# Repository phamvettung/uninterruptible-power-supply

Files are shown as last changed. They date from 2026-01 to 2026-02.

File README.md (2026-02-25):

<div align="center">
 <h1>SUPERVISORY CONTROL AND DATA ACQUISITION ON ELECTRICITY IN INDUSTRIAL PLANTS</h1>
 <h2>HỆ THỐNG ĐIỀU KHIỂN, GIÁM SÁT VÀ THU THẬP DỮ LIỆU ĐIỆN NĂNG TRONG XÍ NGHIỆP CÔNG NGHIỆP</h2>
</div>

## Contents
- [1. Abstract](#i-abstract)
- [2. Design of Uninterruptible Power Supply for an Industrial Plant](#ii-design-of-uninterruptible-power-supply-for-an-industrial-plant)
- [3. Design of Control cabinet](#iii-design-of-control-cabinet)
- [4. SCADA for Power System](#iv-supervisory-control-and-data-acquisition-for-power-system)
- [5. Hidden Markov Model and Forecast Service](#v-hidden-markov-model-and-electricity-usage-forecasting-service)
- [6. Demonstration](#vi-demonstration)
- [7. Requirements](#vii-requirements)
- [8. References](#viii-references)

# I. ABSTRACT
<div>
 <p>This project is a modern SCADA model for the electrical system of an industrial plant. The model is developed based on the TCP/IP protocol, with the advantage stability, flexibility in building your own protocol and real-time communication.</p>
<p>Dự án là mô hình SCADA hiện đại cho một Xí nghiệp công nghiệp. Mô hình được phát triển dựa trên giao thức TCP/IP, với ưu điểm ổn định, linh hoạt trong việc tự định nghĩa giao thức và khả năng truyền thông theo thời gian thực.</p>
</div>

# II. DESIGN OF UNINTERRUPTIBLE POWER SUPPLY FOR AN INDUSTRIAL PLANT
<div>
 <p>Design a power supply for an industrial enterprise comprising 6 workshops, with power sourced from a 22kV connection point. Maximum power usage time Tmax = 5100 hours. Type I and Type II loads account for 75%. The calculated data is shown below.</p>
<p>Thiết kế hệ thống cấp điện cho một Xí nghiệp công nghiệp gồm 6 Phân xưởng, nguồn điện được lấy từ điểm đấu điện của lưới 22kV. Thời gian sử dụng công suất tối đa Tmax = 5100h. Phụ tải loại I, loại II chiếm 75%. Các số liệu tính toán được thể hiện ở bên dưới.</p>
<p align="center">
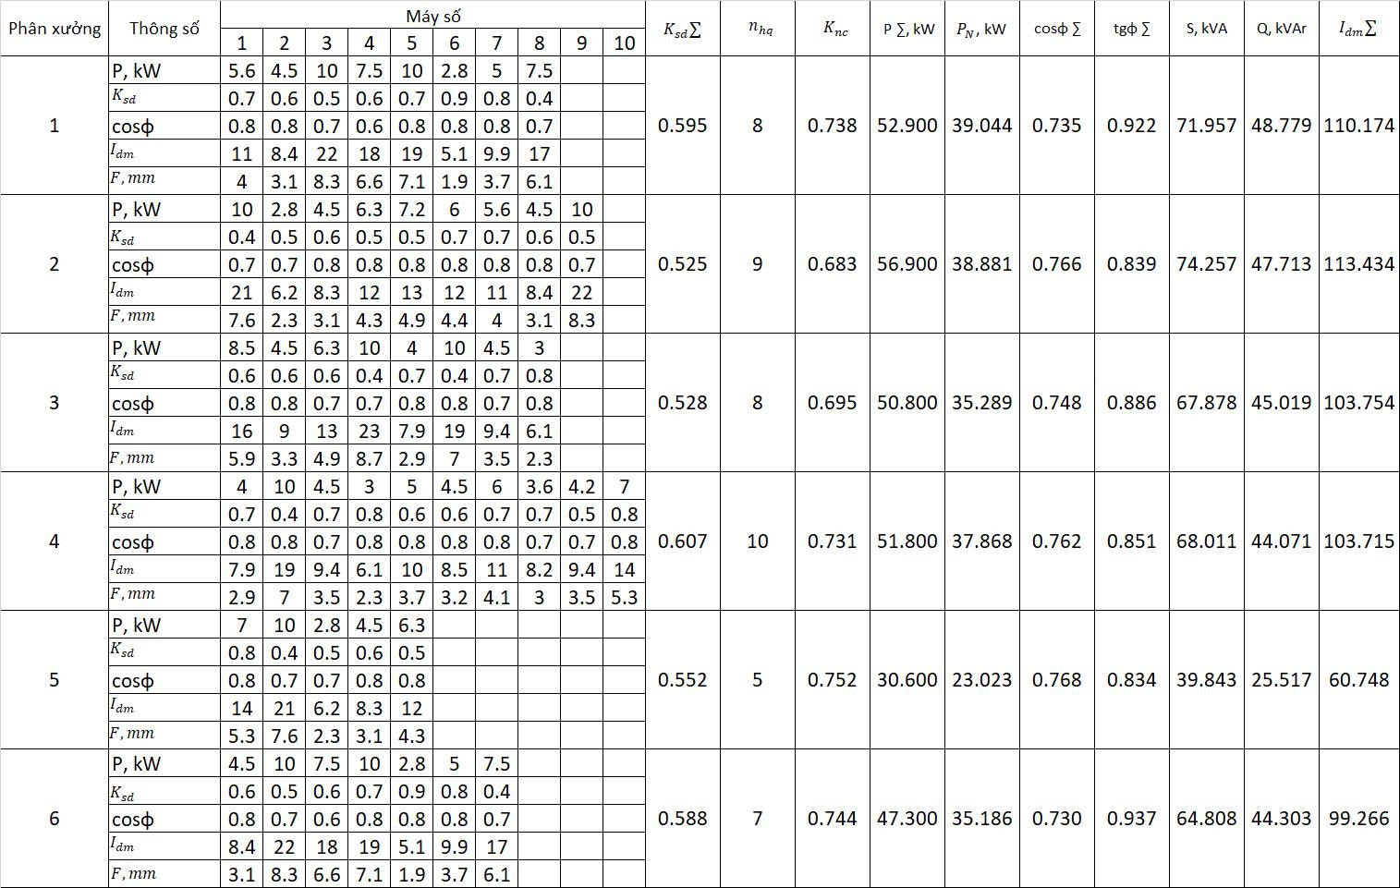
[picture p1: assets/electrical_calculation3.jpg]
  
</p>

#### a. Xác định phụ tải tính toán của toàn Xí nghiệp

**- Hệ số sử dụng của toàn Xí nghiệp:**

$$
K_{sd}XN = \frac{\sum (S_i \times K_{sd,i})}{\sum S_i} = 0.566
$$

**- Hệ số nhu cầu của Xí nghiệp:**

$$
K_{nc}XN = 0.566 + \frac{(1 - 0.566)}{\sqrt(6)} = 0.743
$$

**- Hệ số công suất trung bình của toàn Xí nghiệp:**

$$
\cos \varphi XN = \frac{\sum (S_i \times \cos_{\varphi,i})}{\sum S_i} = 0.75 => \sin \varphi = \sqrt{1-\cos^2 \varphi} = 0.66
$$

**- Tổng công suất tính toán của toàn Xí nghiệp:**

$$
S_{XN} = K_{nc}XN \times \sum S_i = 0.743 \times 386.75 = 287.48 kVA
$$

$$
P_{XN} = S_{XN} \times \cos \varphi_{XN} = 0.75 \times 287.48 = 215.781 kW
$$

$$
Q_{XN} = S_{XN} \times \sin \varphi_{XN} = 0.66 \times 287.48 = 189.95 kVAr
$$

**- Chọn dây dẫn từ nguồn đến trạm biến áp:**

>>Dòng điện chạy trên dây dẫn

$$
   I = \frac{S_{XN}}{\sqrt(3) \times U} = \frac{287.48}{\sqrt(3) \times 22} = 7.544 A
$$

>>Tiết diện dây nhôm theo mật độ dòng điện kinh tế (Jkt = 1.2 A/mm2). Đối với đường dây cao áp tiết diện tối thiểu không nhỏ hơn 35mm2 => Ta chọn dây AC-35 nối từ nguồn vào trạm biến áp

$$
   F = \frac{I}{J_{kt}} = \frac{7.544}{1.2} = 6.28 \text{mm}^2
$$

#### b. Chọn máy biến áp

>>Ta có tổng công suất tính toán toàn Xí nghiệp (chưa kể đến hao tổn công suất trên đường đây) = 287.48 kVA, thời gian sử dụng công suất tối đa = 5100 h

**- Công suất trung bình**

$$
   S_{tb} = \frac{S_{XN} \times T_{max}}{8760} = \frac{287.48 \times 5100}{8760} = 167.36 kVA
$$

**- Hệ số điền kín đồ thị phụ tải = 0.58 < 0.75. Như vậy máy biến áp có thể làm việc quá tải 40% (kqt = 1.4) trong một thời gian xác định**

$$
   k_{đk} = \frac{S_{tb}}{S_{XN}} = \frac{167.63}{287.48} = 0.58
$$

=> Chọn 02 máy biến áp có công suất định mức 2 x 250 kVA, hệ số quá tải = 0.99 nhỏ hơn 1.4 => đảm bảo yêu cầu

$$
   k_{qt}= \frac{S_{XN}}{S_{nBA}} = \frac{287.48}{250} = 0.99 < 1.4
$$

**- Tham số của máy biến áp dòng THIBIDI: công suất định mức 250 kVA, điện áp ngắn mạch phần trăm Uk% = 4**

>>Tổn hao công suất không tải và tổn hao ngắn mạch (P0, Pk)

$$
   \Delta P_{0}= 0.34 kW
$$

$$
   \Delta P_{k}= 2.6 kW
$$

**- Tính toán trong máy biến áp:**

>>Dòng điện định mức của biến áp:

$$
   I_{đm}BA = \frac{S_{đm}BA}{\sqrt(3) \times U} = \frac{250}{\sqrt(3) \times 0.4} = 360.84 A
$$

>>Điện trở biến áp

$$
   R_{BA} = \frac{\Delta P_k}{3 \times I_{đm}^2} = \frac{2.6}{3 \times 360.84^2} = 0.0067 \Omega
$$

>>Tổng trở biến áp

$$
   Z_{BA} = \frac{\Delta U_k \cdot U^2}{100 * S_{BA}} = \frac{4 \cdot 0.4^2}{100 * 250} = 0.0256 \Omega
$$

>>Điện kháng biến áp

$$
   X_{BA} = \sqrt(0.0067^2 - 0.0256^2) = 0.0247 \Omega
$$

**- Tính toán ngắn mạch:**

>>Dòng điện ngắn mạch 3 pha tại thanh cái hạ áp của biến áp (N1):

$$
   I_{sc}N1= \frac{I_{đm}BA}{Uk%} = \frac{360.84}{0.04} = 9.021 kA
$$

>>Tính toán ngắn mạch cho phụ tải ở xa trạm biến áp nhất (Phân xưởng 01, điểm N2): dây đồng 35mm2, chiều dài 160m, điện trở suất dây đồng = 0.0178, điện kháng Xd = 0.00008

$$
   R_{tổng} = R_{BA} + \rho \times \frac{l}{35} = 0.0067 + 0.0813 = 0.088 \Omega
$$

$$
   X_{tổng} = X_{BA} + Xd \times l = 0.0247 + 0.00008 \times 160 = 0.0357 \Omega
$$

$$
   Z_{tổng} = \sqrt((0.088)^2 + (0.0357)^2) = 0.094 \Omega
$$

>>Dòng điện ngắn mạch 3 pha tại điểm N2:

$$
   I_{sc}N2 = \frac{U}{\sqrt(3) \times Z_{tổng}} = \frac{400}{\sqrt(3) \times 0.094} = 2.45 kA
$$

#### c. Chọn thanh cái hạ áp của trạm biến áp

**- Dòng điện chạy qua thanh cái**

$$
   I = \frac{S_{XN}}{\sqrt(3) \times U} = \frac{287.47}{\sqrt(3) \times 0.4} = 414.93 A
$$

>>Chọn thanh cái dẹt bằng đồng có Jkt = 1.8 A/mm2, kích thước 50x6 = 300 mm2

$$
   F = \frac{I}{J_{kt}} = \frac{414.93}{1.8} = 230.51 \text{mm}^2
$$

<h3>1. Selecting MCCB and ACB</h3>
 <table align="center">
  <thead>
    <tr>
      <th>Cabinet ID</th>
      <th>Cabinet Name</th>
      <th>Device Name</th>
      <th>Itt, A</th>
      <th>In, kA</th>
      <th>UdmCB, V</th>
      <th>IdmCB, A</th>
      <th>InCB, kA</th>
      <th>Manufacture</th>
      <th>Type</th>
      <th>Code</th>
    </tr>
  </thead>
  <tbody>
    <tr>
      <td>TPP01</td>
      <td>Tủ Phân phối 01</td>
      <td>ACB 01</td>
      <td>414.93</td>
      <td>9.021</td>
      <td>690</td>
      <td>630</td>
      <td>65</td>
      <td>MITSUBISHI</td>
      <td>NCT06</td>
      <td>AE630-SW</td>
    </tr>
    <tr>
      <td>TPP02</td>
      <td>Tủ Phân phối 02</td>
      <td>ACB 02</td>
      <td>414.93</td>
      <td>9.021</td>
      <td>690</td>
      <td>630</td>
      <td>65</td>
      <td>MITSUBISHI</td>
      <td>NCT06</td>
      <td>AE630-SW</td>
    </tr>
    <tr>
      <td>MC 03</td>
      <td>Máy Cắt 03</td>
      <td>ACB 03</td>
      <td>414.93</td>
      <td>9.021</td>
      <td>690</td>
      <td>630</td>
      <td>65</td>
      <td>MITSUBISHI</td>
      <td>NCT06</td>
      <td>AE630-SW</td>
    </tr>
    <tr>
      <td>MDB 01</td>
      <td>Tủ Phân xưởng 01</td>
      <td>MCCB 01</td>
      <td>110.17</td>
      <td>2.45</td>
      <td>690</td>
      <td>160</td>
      <td>36</td>
      <td>MITSUBISHI</td>
      <td>NF-S TYPE</td>
      <td>NF250-SV</td>
    </tr>
    <tr>
      <td>MDB 02</td>
      <td>Tủ Phân xưởng 02</td>
      <td>MCCB 02</td>
      <td>113.43</td>
      <td>2.45</td>
      <td>690</td>
      <td>160</td>
      <td>36</td>
      <td>MITSUBISHI</td>
      <td>NF-S TYPE</td>
      <td>NF250-SV</td>
    </tr>
    <tr>
      <td>MDB 03</td>
      <td>Tủ Phân xưởng 03</td>
      <td>MCCB 03</td>
      <td>103.75</td>
      <td>2.45</td>
      <td>690</td>
      <td>160</td>
      <td>36</td>
      <td>MITSUBISHI</td>
      <td>NF-S TYPE</td>
      <td>NF250-SV</td>
    </tr>
    <tr>
      <td>MDB 04</td>
      <td>Tủ Phân xưởng 04</td>
      <td>MCCB 04</td>
      <td>103.71</td>
      <td>2.45</td>
      <td>690</td>
      <td>160</td>
      <td>36</td>
      <td>MITSUBISHI</td>
      <td>NF-S TYPE</td>
      <td>NF250-SV</td>
    </tr>
    <tr>
      <td>MDB 05</td>
      <td>Tủ Phân xưởng 05</td>
      <td>MCCB 05</td>
      <td>60.74</td>
      <td>2.45</td>
      <td>690</td>
      <td>160</td>
      <td>36</td>
      <td>MITSUBISHI</td>
      <td>NF-S TYPE</td>
      <td>NF250-SV</td>
    </tr>
    <tr>
      <td>MDB 06</td>
      <td>Tủ Phân xưởng 06</td>
      <td>MCCB 06</td>
      <td>99.26</td>
      <td>2.45</td>
      <td>690</td>
      <td>160</td>
      <td>36</td>
      <td>MITSUBISHI</td>
      <td>NF-S TYPE</td>
      <td>NF250-SV</td>
    </tr>
  </tbody>
</table>
 <h3>2. Principle diagram of the distribution station</h3>
 <p>The distribution substation is designed with two 250 kVA, Y/Y, 22/0.4kV transformers connected to busbars C1 and C2 of size 50x6 mm2. The conductors from the power source to the substation are AC-35 aluminum wires.. A connecting circuit breaker (ACB 03) connects two busbars. In case of a fault or when maintenance or transformer replacement is needed. One of the two Circuit breakers will trip, and Circuit breaker 03 will close to power supply on the other side.</p>
 <p>Trạm phân phối được thiết kế với 02 máy biến áp 250 kVA, Y/Y, 22/0.4kV kết nối tới 02 thanh cái C1 và C2 kích thước 50x6 mm2, dây dẫn từ nguồn tới trạm biến áp là dây nhôm AC-35. Một máy cắt liên lạc ACB 03 nối giữa 2 thanh cái. Khi có sự cố hay cần bảo trì, thay thế máy biến áp, 1 trong 2 máy cắt ngắt điện, máy cắt 03 sẽ đóng để cấp nguồn cho các phụ tải phía bên kia.</p>
 <p align="center">
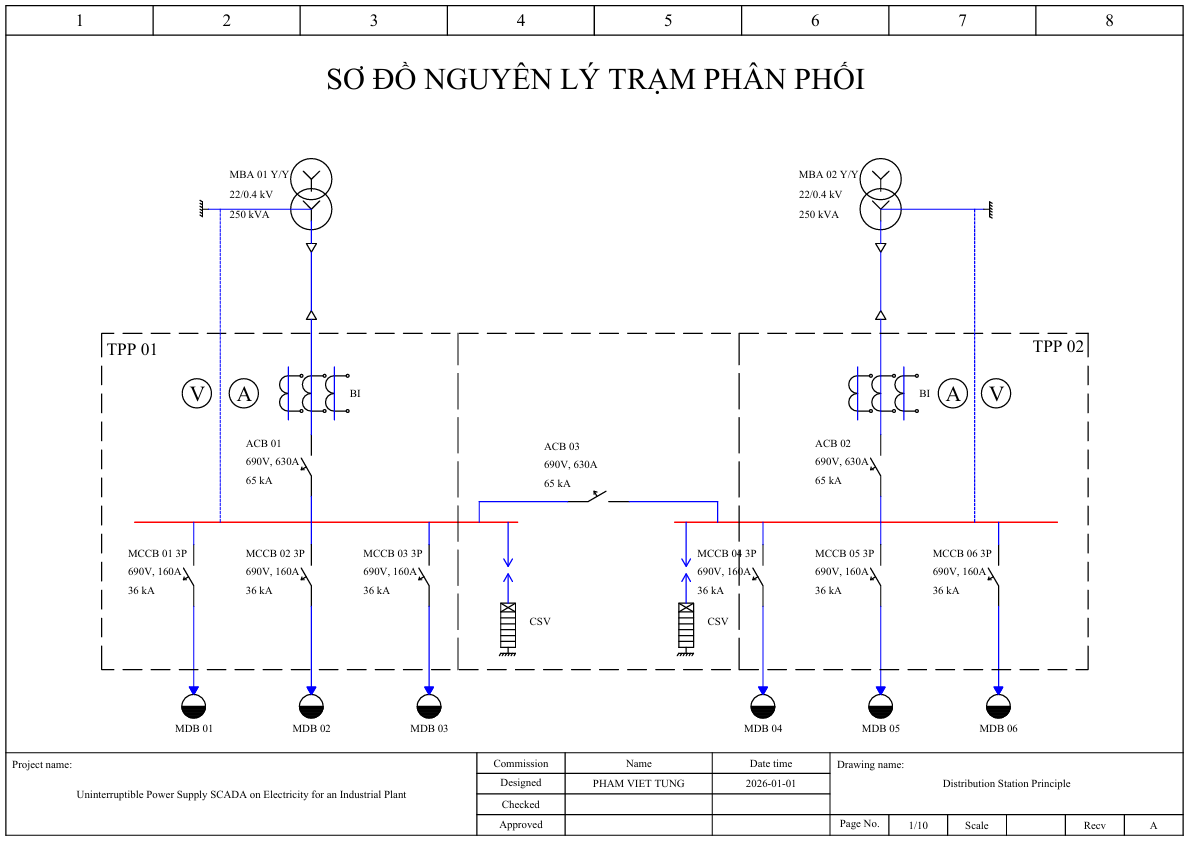
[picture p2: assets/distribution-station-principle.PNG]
  
</p>
</div>

# III. DESIGN OF CONTROL CABINET
<div>
 <p>In this project, a PLC FX5UJ is used to control 03 main circuit breakers. Retrieve the on/off status of 03 ACBs and 06 MCCBs. The FX5-485ADP module is used to communicate with the electricity meters via the RS-485 protocol. College data of the current, voltage, power, energy consumption.</p>
 <p>Dự án sử dụng PLC FX5UJ để điều khiển 03 máy cắt chính. Nhận tín hiệu trạng thái ON/OFF của 03 ACB và 06 MCCB. Module truyền thông FX5-485ADP được sử dụng để kết nối với các đồng hồ đo điện, thu thập dữ liệu năng lượng: dòng điện, điện áp, công suất tức thời, điện năng tiêu thụ.</p>
<h3>1. Control cabinet layout</h3>
 <p align="center">
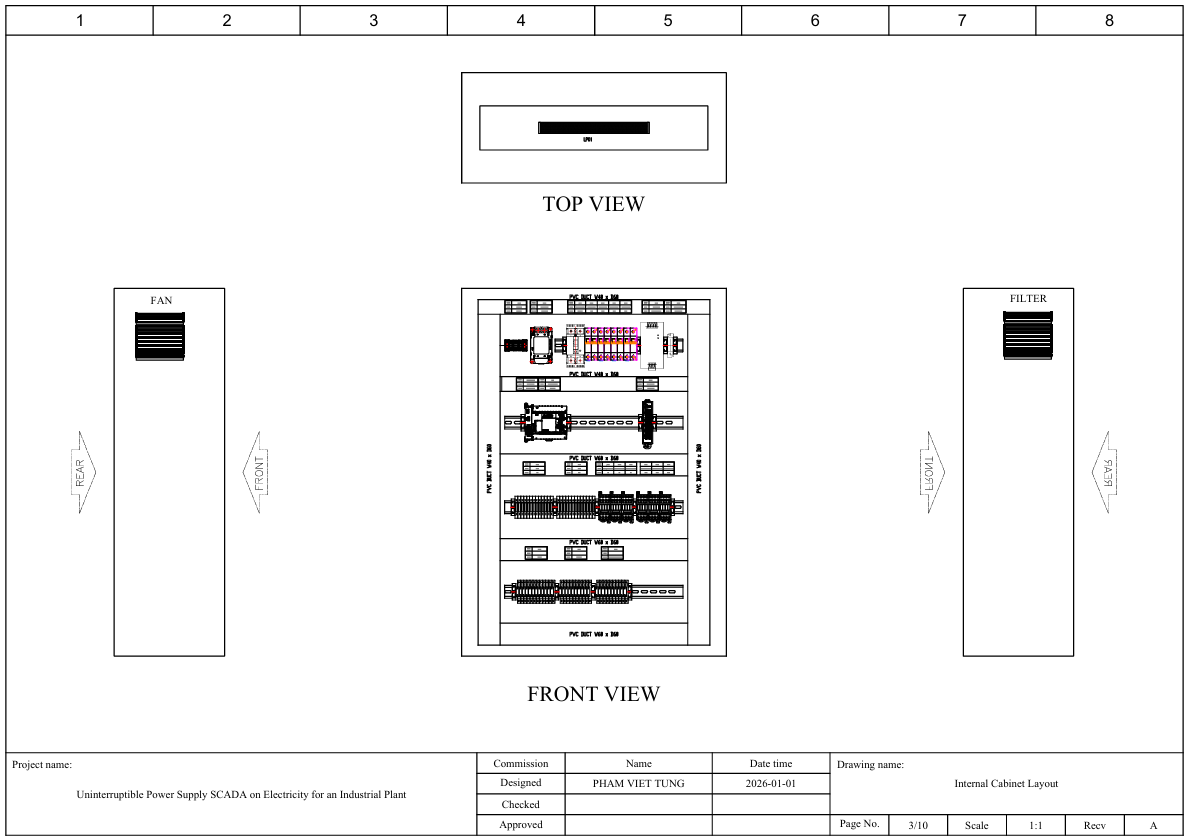
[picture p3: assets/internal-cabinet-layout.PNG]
  
</p>
 <h3>2. AC Power Distribution</h3>
 <p align="center">
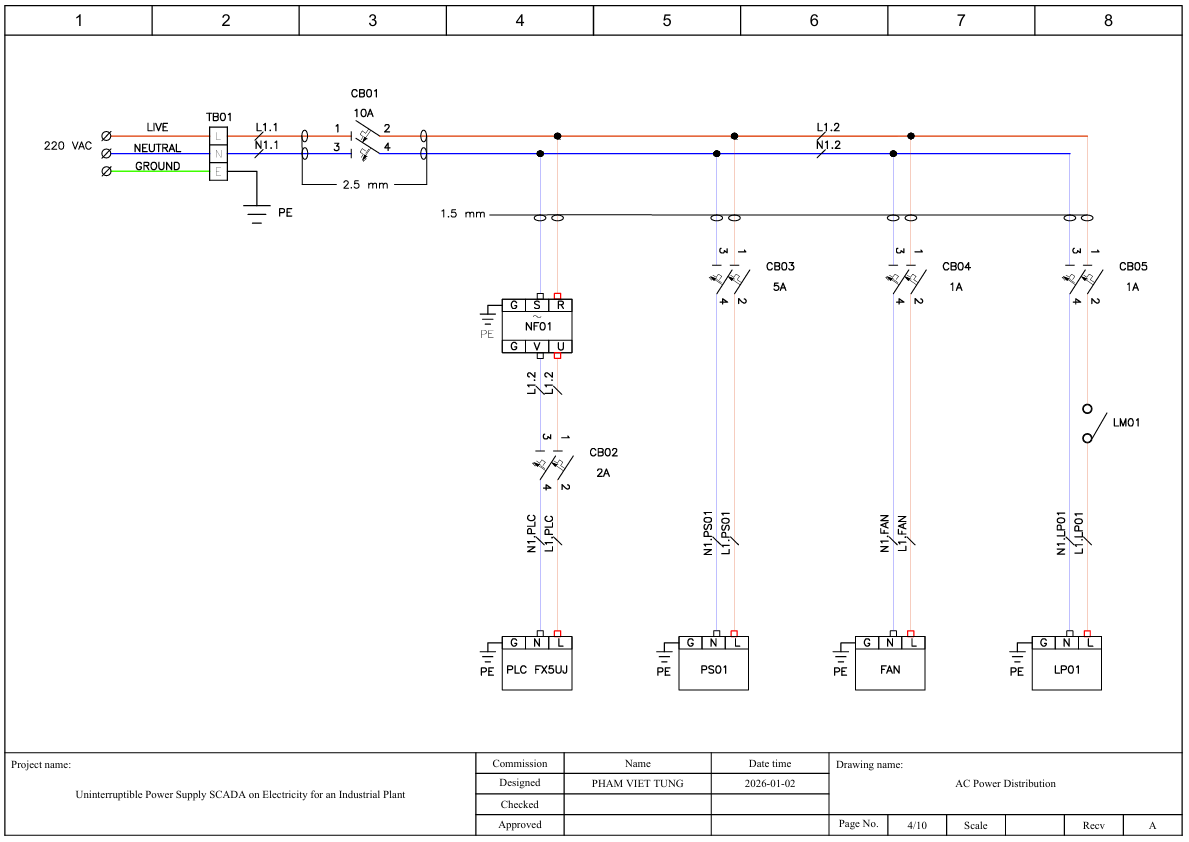
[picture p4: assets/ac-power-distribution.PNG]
  
</p>
  <h3>3. DC Power Distribution</h3>
 <p align="center">
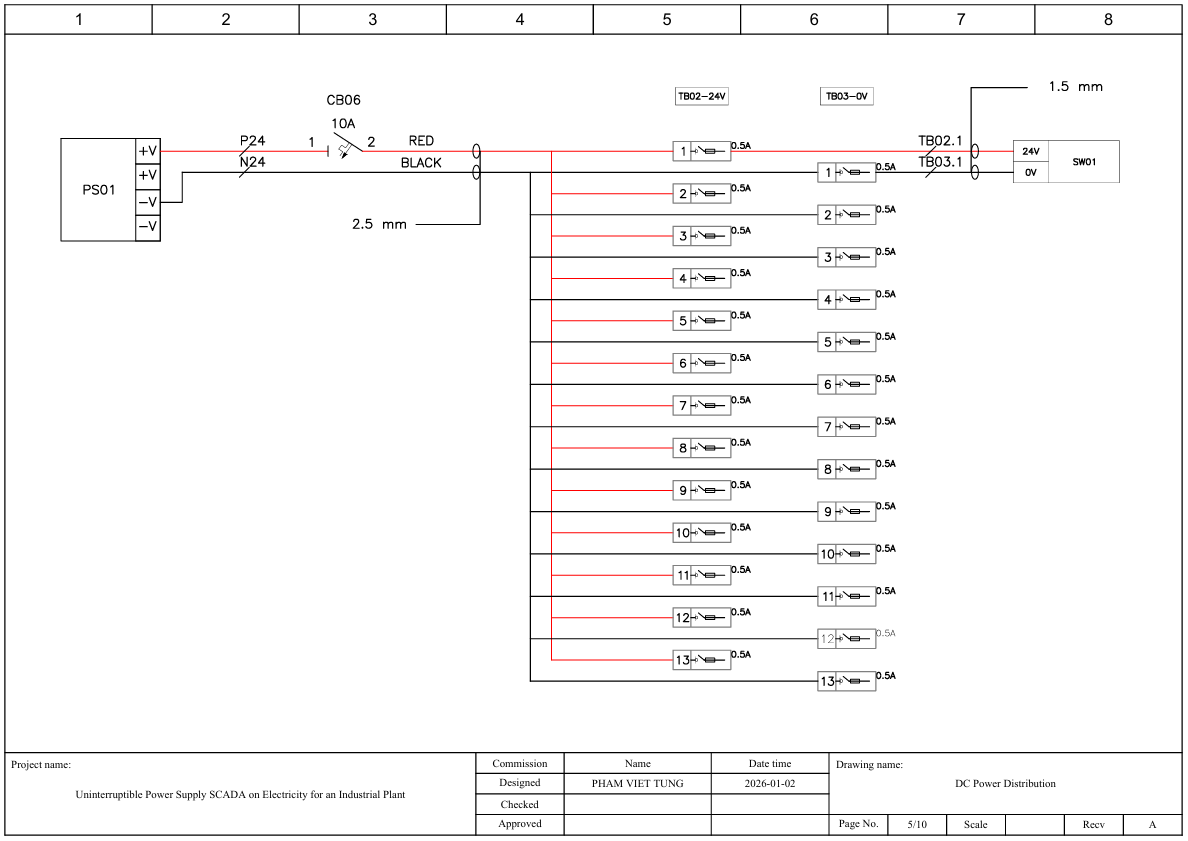
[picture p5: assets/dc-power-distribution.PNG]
  
</p>
<h3>4. Input wiring</h3>
 <p align="center">
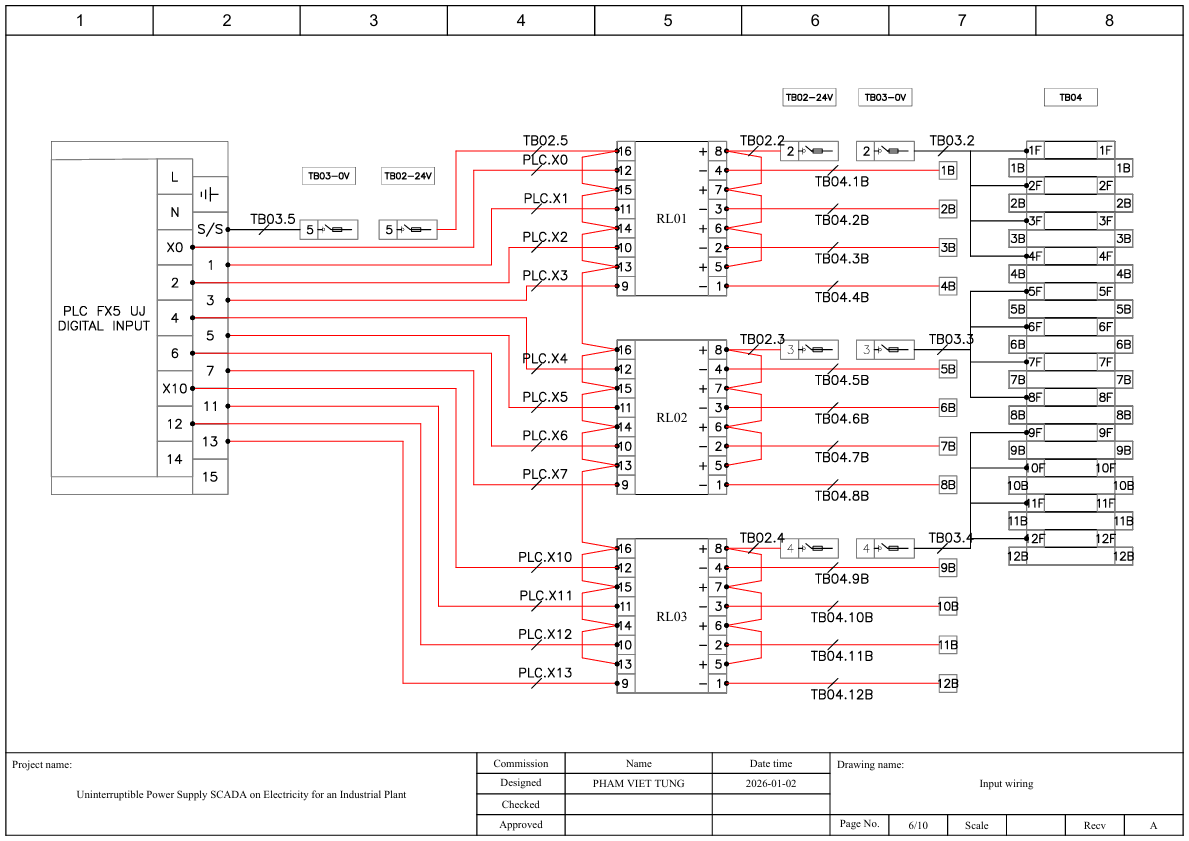
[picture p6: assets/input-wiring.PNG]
  
</p>
<h3>5. Output wiring</h3>
 <p align="center">
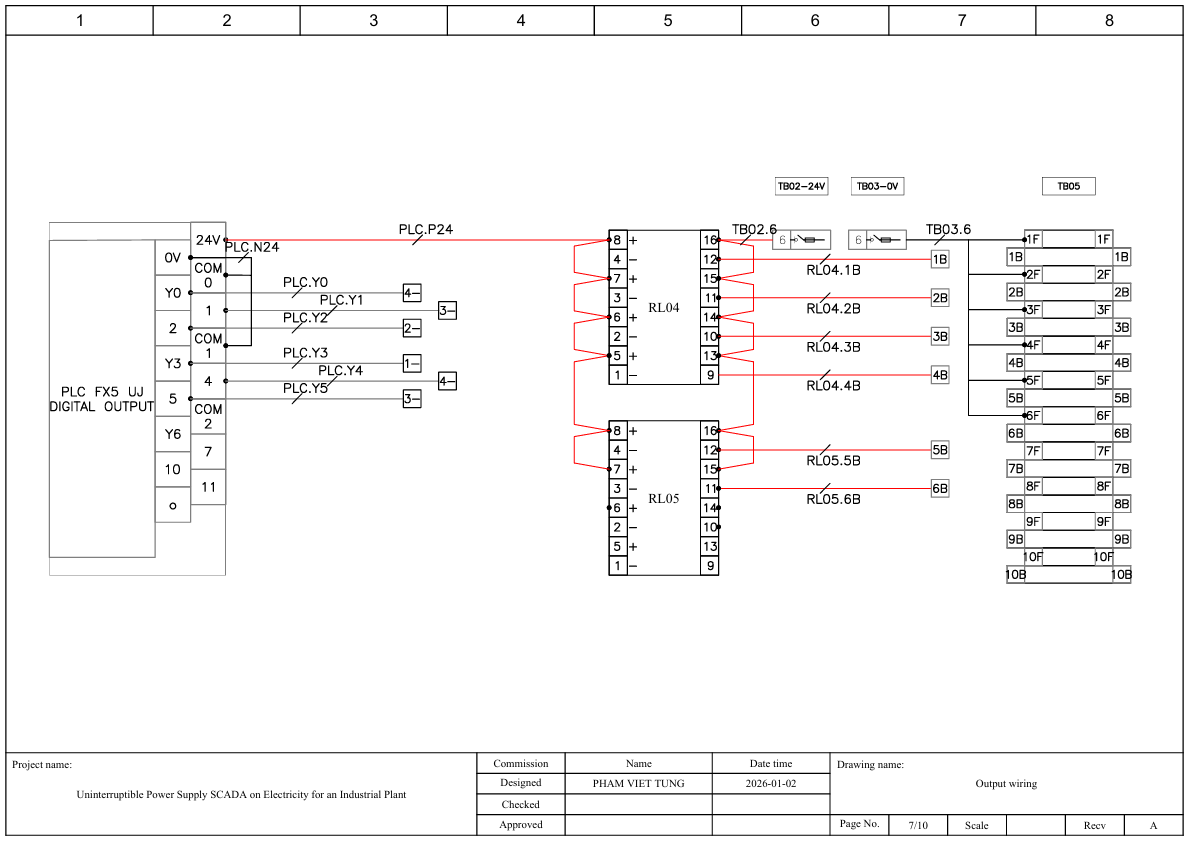
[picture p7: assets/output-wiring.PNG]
  
</p>
 <h3>6. Terminal to ACBs and MCCBs</h3>
 <p align="center">
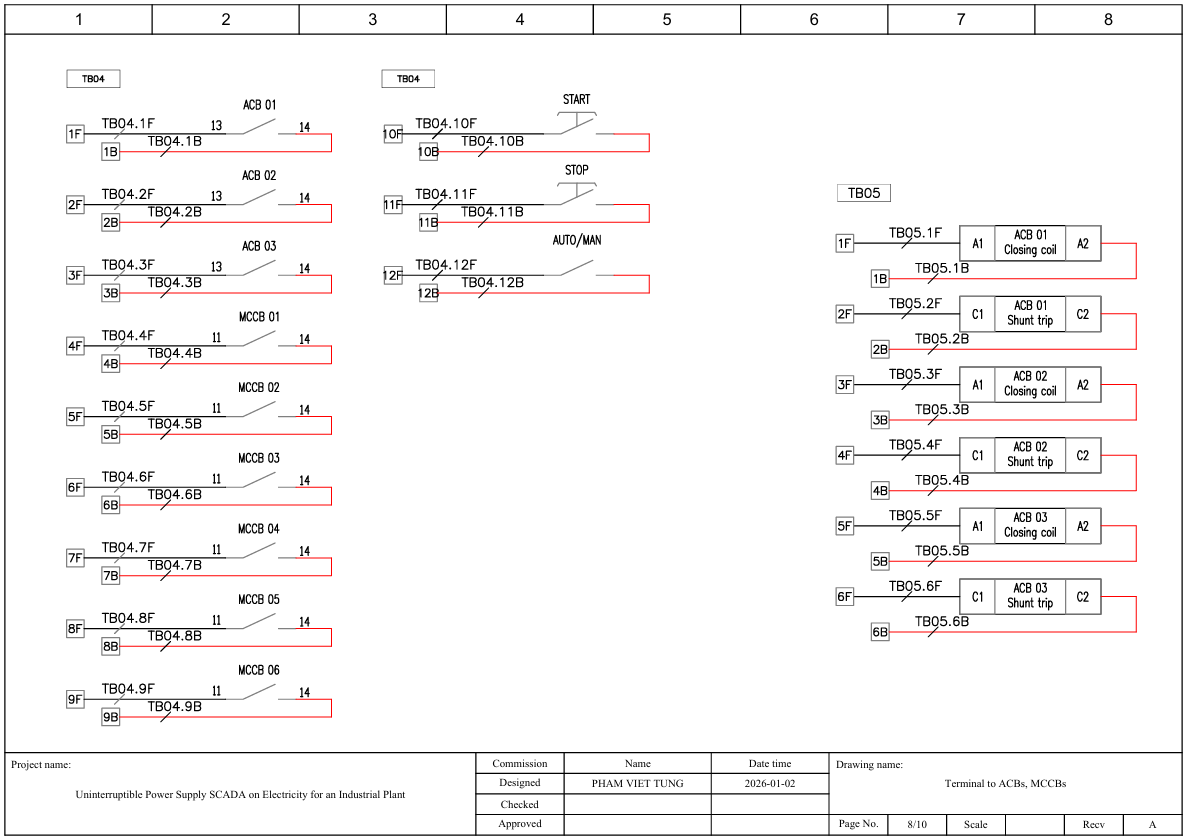
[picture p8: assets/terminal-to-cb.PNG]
  
</p>
 <h3>7. Fx5-485ADP to the electrical meters</h3>
 <p align="center">
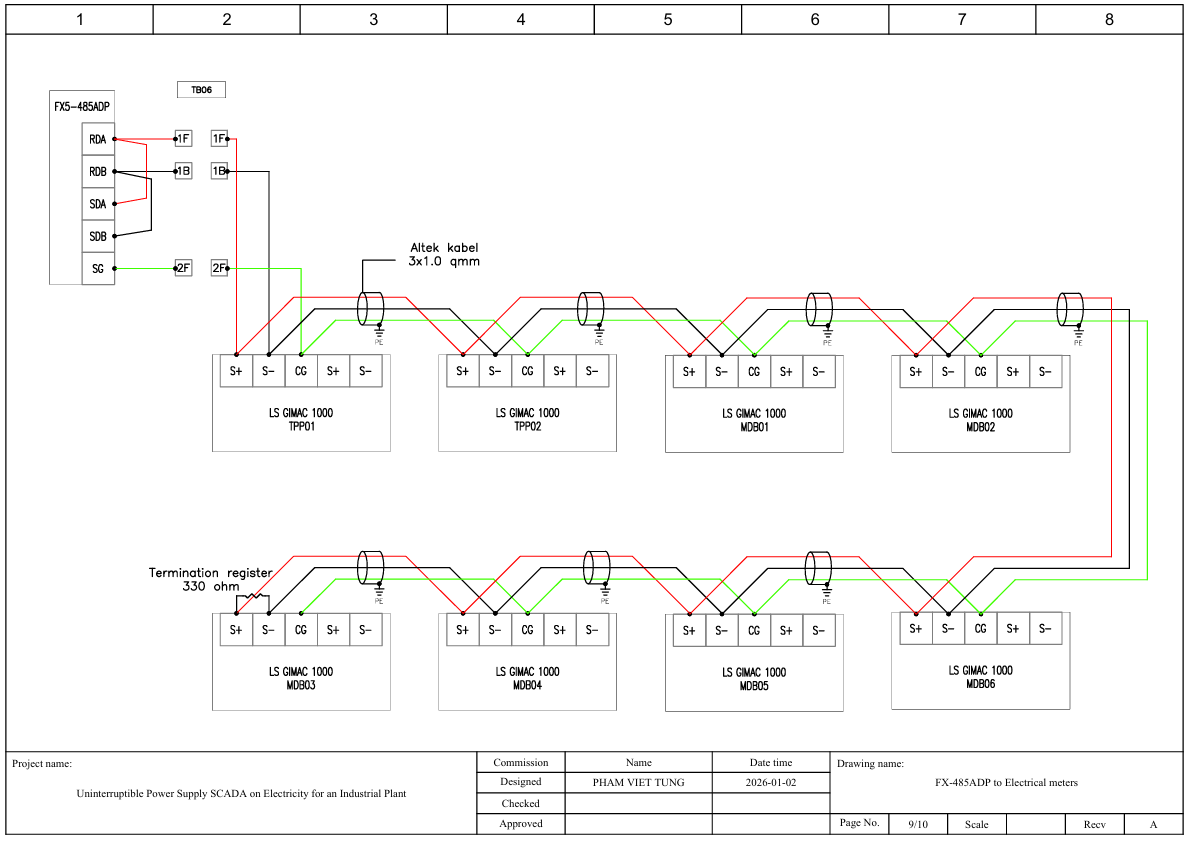
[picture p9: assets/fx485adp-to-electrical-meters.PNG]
  
</p>
</div>

# IV. SUPERVISORY CONTROL AND DATA ACQUISITION FOR POWER SYSTEM
<div>
  <p>The SCADA software used to control and monitor equipment remotely via a Web browser. Energy data is collected automatically in real time. All the technologies used and communication protocols are presented below.</p>
 <p>Phần mềm SCADA sử dụng để điều khiển, giám sát trạng thái của thiết bị từ xa trên trình duyệt Web. Dữ liệu về năng lượng được thu thập tự động theo thời gian thực. Các công nghệ sử dụng và giao thức truyền thông được mô tả bên dưới đây.</p>
 
<h3>1. Diagram and Technologies used</h3>
<p>The PLC controller communicates with the web server via a TCP/IP. The server provides APIs and WebSockets for the users side to send and receive data.The PLC connects to Field equipment via RS-485 communication standard and input/output ports on PLC.</p>
<p>The Web Server-side (back-end) is built on Spring Boot Framework. Web application-side (front-end) is built on ReactJS. This project uses the MySQL and Redis database management system - resulting in fast query speeds and enhance the requests from the Clients.</p>
<p>The model for analyzing and forecasting is separated into a distinct microservice. It has 3 main functions: predict state, anomaly detection, forecast electricity usage in the future.</p>
 <p>PLC kết nối tới Web Server thông qua TCP/IP. Web Server cung cấp các API và WebSocket để User có thể gửi và nhận dữ liệu. PLC truyền thông với các đồng hồ điện sử dụng Modbus RS-485 và kết nối tới các tiếp điểm phụ của ACB, MCCB thông qua các cổng input, output của PLC.</p>
<p>Web Server và Web application được xây dựng trên nền tảng Spring Boot và thư viện ReactJS. Dự án sử dụng Hệ quản trị cơ sở dữ liệu MySQL và Redis - giúp cho tốc độ truy vấn nhanh, tăng hiệu suất xử lý các yêu cầu của Client.</p>
<p>Mô hình phân tích dữ liệu và dự báo được tách thành một microservice riêng. Có 3 chức năng chính: phân tích trạng thái hệ thống, phát hiện bất thường và dự báo mức sử dụng điện trong tương lai.</p>
<p align="center">
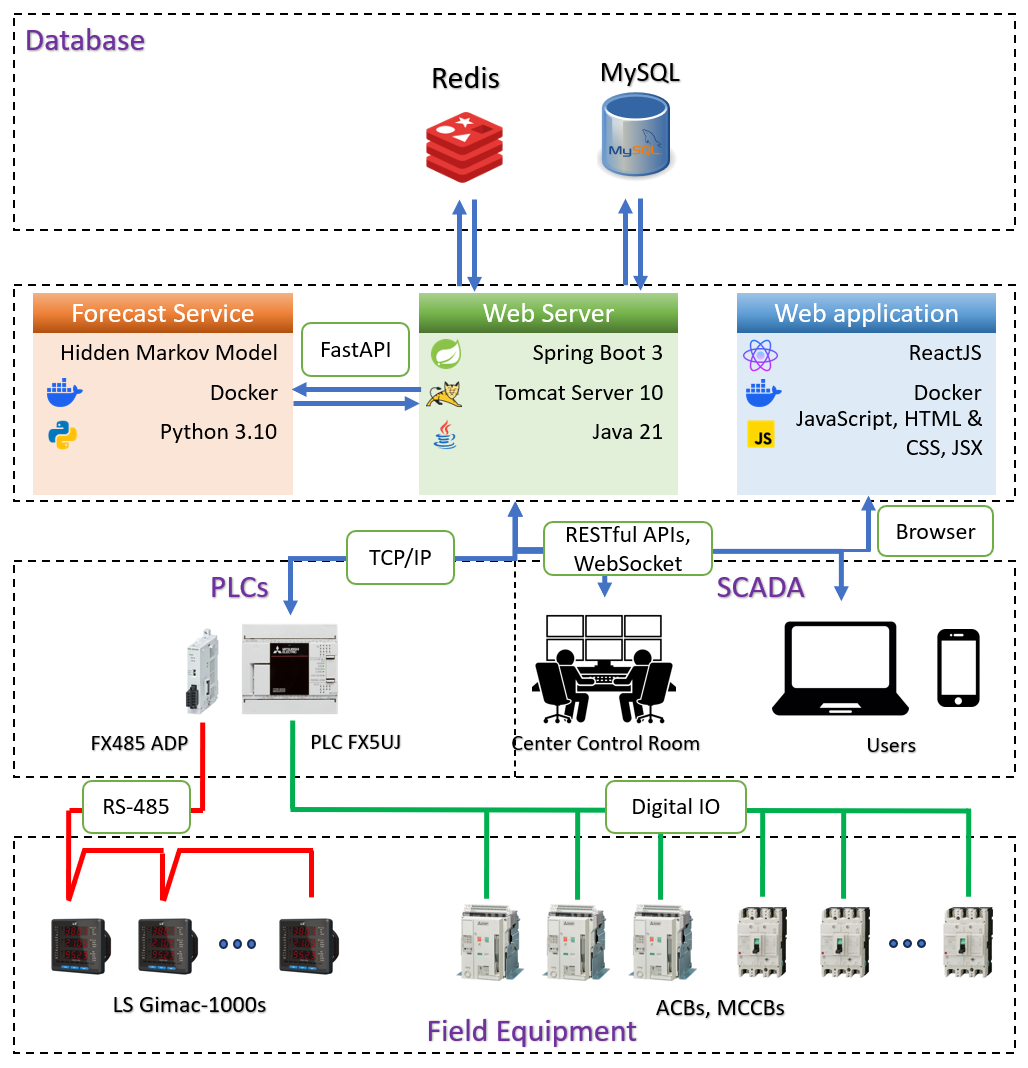
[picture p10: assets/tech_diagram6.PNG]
  
</p>

<h3>2. Table structure in Database</h3>
<p>The database management system used in the project is MySQL, which includes 10 tables:</p>
<ul>
  <li>Tables users, user_role, role: for security, authentication, and user authorization features.</li>
  <li>Table cabinet: for managing electrical cabinets (TPP, MDB).</li>
  <li>Table device: for managing devices (ACB, MCCB).</li>
  <li>Table energy: for collecting energy data.</li>
  <li>Table tokens: for storing refresh token.</li>
  <li>Table alarm, alarm_type, alarm_history: for alarm feature.</li>
</ul>
<p>Hệ quản trị cơ sở dữ liệu sử dụng trong dự án là MySQL gồm 10 bảng:</p>
<ul>
  <li>Bảng users, user_role, role: cho tính năng bảo mật, xác thực và phân quyền người dùng.</li>
  <li>Bảng cabinet: quản lý tủ điện (TPP, MDB).</li>
  <li>Bảng device: quản lý thiết bị (ACB, MCCB).</li>
  <li>Bảng energy: thu thập dữ liệu về năng lượng.</li>
  <li>Bảng tokens: lưu trữ refresh token.</li>
  <li>Bảng alarm, alarm_type, alarm_history: cho tính năng cảnh báo.</li>
</ul>
<p align="center">
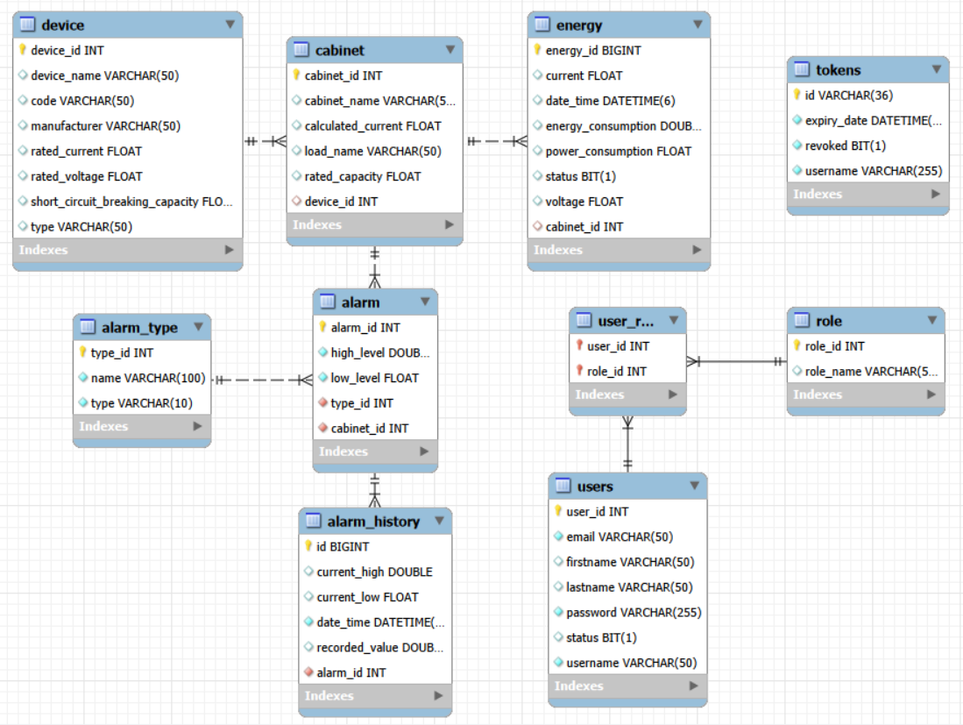
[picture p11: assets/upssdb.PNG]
  
</p>

<h3>3. Authentication, Authorization and Security (Spring Security JWT)</h3>
<p>SCADA software provides authentication features, user authorization and APIs security to protect applications from common threats such as CSRF, XSS, etc.</p>
<p>Phần mềm SCADA cung cấp các tính năng xác thực (ai là user), phân quyền (bạn được phép làm gì) và bảo mật các API để bảo vệ ứng dụng khỏi các mối đe dọa phổ biến như CSRF, XSS, etc. </p>
<p align="center">
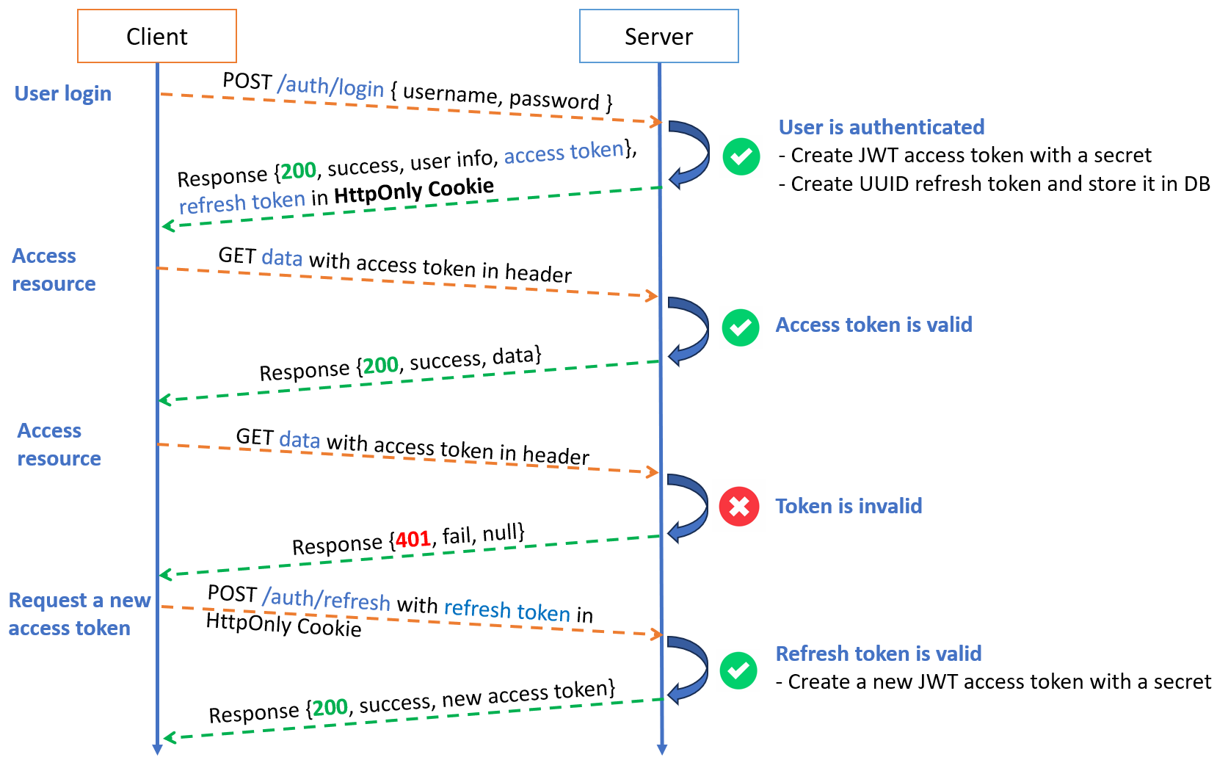
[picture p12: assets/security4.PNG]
  
</p>

<h3>4. PLC-Server Protocol</h3>
<p>A message used to transmit and receive data between a PLC and a server is defined by a byte array. Each message sent has a start (STX) and end character (ETX).</p>
<p>Một bức điện có định dạng là mảng các byte dùng để truyền và nhận dữ liệu giữa PLC và Server. Mỗi bức điện gửi đi đều có kí tự bắt đầu (STX) và kí tự kết thúc (ETX).</p>
<p align="center">
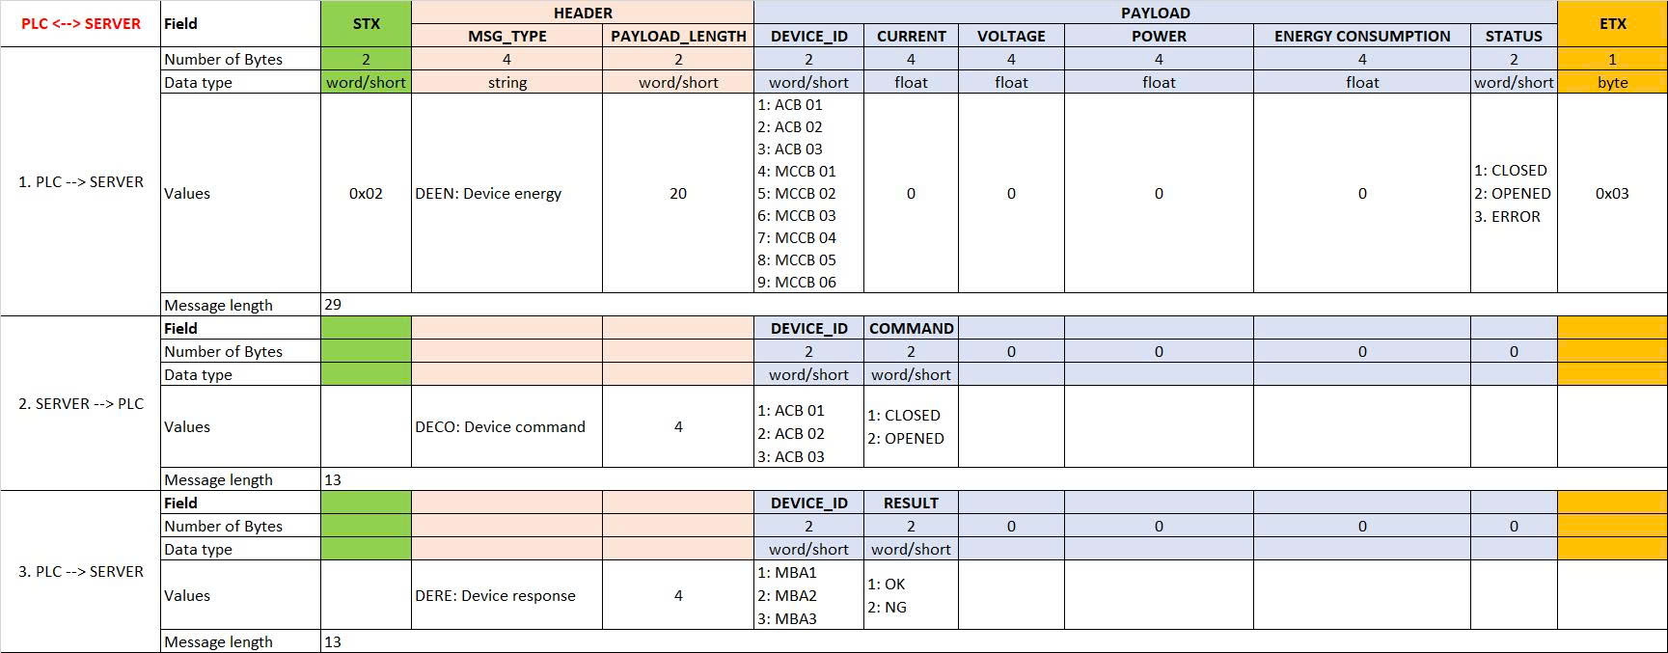
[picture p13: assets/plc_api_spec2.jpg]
  
</p>

<h3>5. Server-User Protocol</h3>
<p>The messages sent and received between the server and the user are in the format of a JSON like this.</p>
<p>Thông điệp để truyền và nhận dữ liệu giữa Server và User có định dạng là một chuỗi JSON như bên dưới.</p>

```sh
{
 "messageType": "DEEN",
 "data": {
    "deviceId": 1,
    "current": 6,
    "voltage": 380,
    "power": 2280,
    "energy": 10000,
 }
}
```
<h3>6. Dashboard</h3>
<p>The Dashboard page displays a monthly energy consumption breakdown for the year, yesterday's and today's energy usage, and the electricity bill amount.</p>
<p>Trang Dashboard hiển thị bảng thống kê điện năng hàng tháng trong năm, mức tiêu thụ điện năng ngày hôm qua và trong ngày hôm nay, cùng với số tiền điện phải chi trả. Giao diện SCADA còn cho phép cài đặt chế độ hiển thị sáng/tối, chọn ngôn ngữ hiển thị Tiếng Việt/Tiếng Anh.</p>
<p align="center">
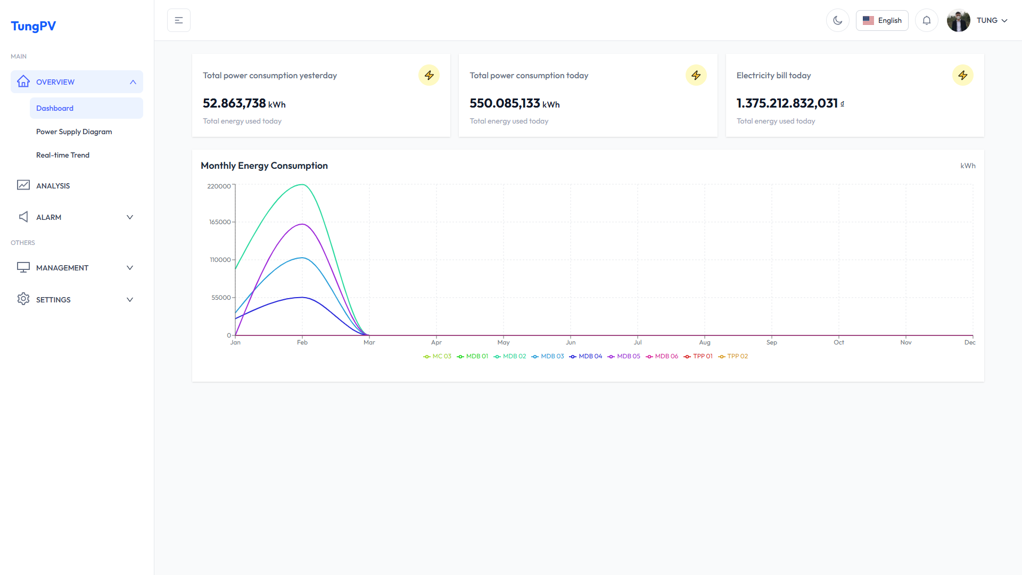
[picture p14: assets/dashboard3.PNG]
  
</p>

<h3>7. Power Supply Diagram</h3>
<p>The Power Supply Diagram page displays the principle diagram of the distribution substation with the parameters of the connected devices in the circuit. It displays energy data and controls for opening/closing the ACBs.</p>
<p>Trang Power Supply Diagram cung cấp sơ đồ nguyên lý của trạm phân phối và các thông số của thiết bị điện. Hiển thị giá trị năng lượng tức thời và có thể điều điều khiển AUTO/MANUAL đóng, ngắt 03 máy cắt.</p>
<p align="center">
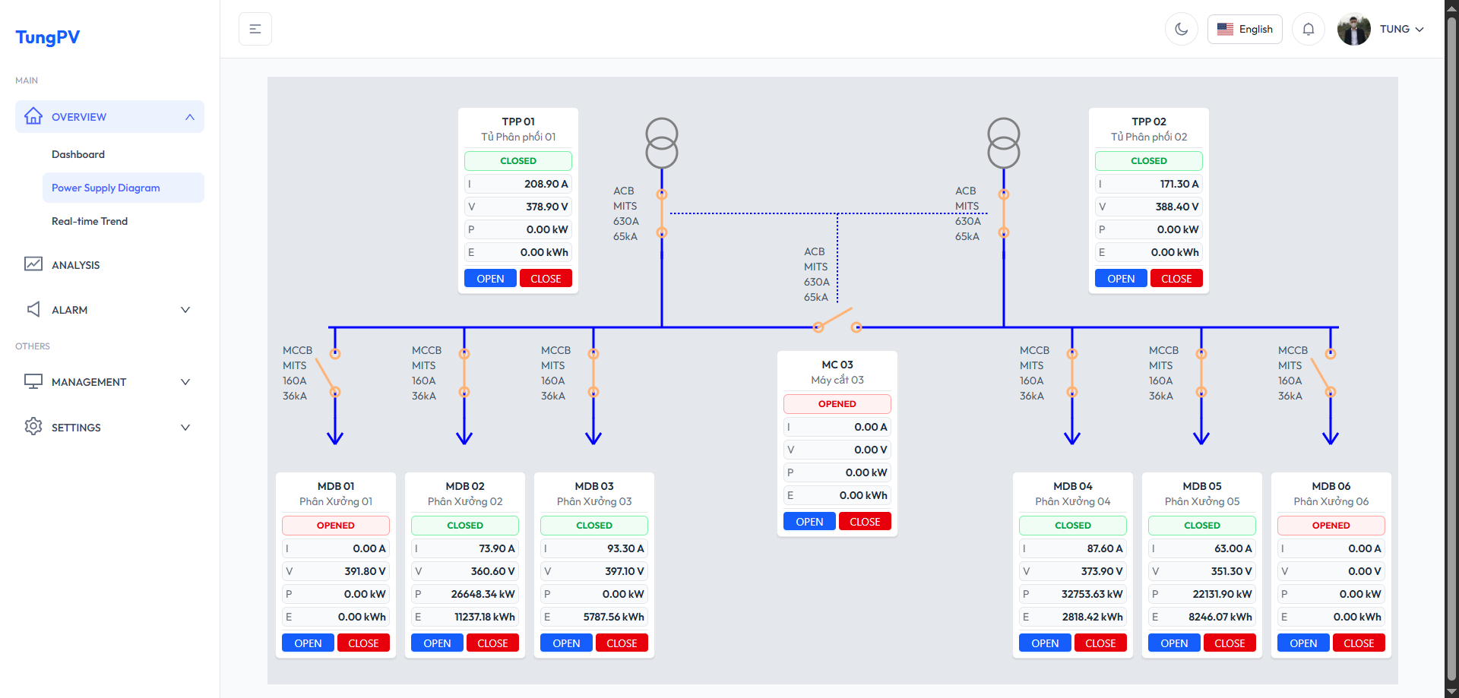
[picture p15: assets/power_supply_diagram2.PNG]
  
</p>

<h3>8. Real-time Trend</h3>
<p>The Real-time Trend page displays energy graphs of loads: instantaneous current, instantaneous voltage, power consumption, and energy consumption over time.</p>
<p>Trang Real-time Trend hiển thị biểu đồ năng lượng của từng Phân xưởng: Dòng điện tức thời, điện áp tức thời, công suất tiêu thụ và điện năng tiêu thụ theo thời gian thực.</p>
<p align="center">
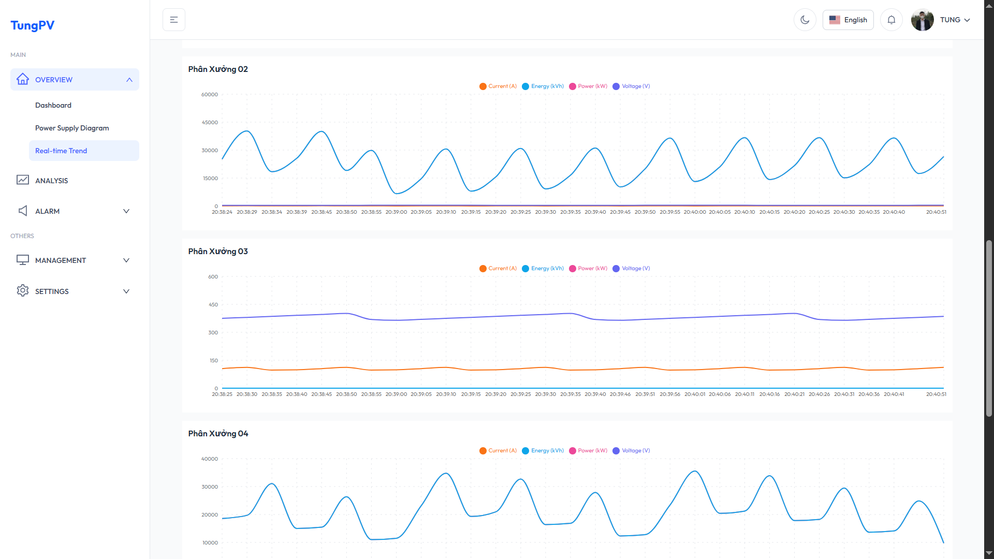
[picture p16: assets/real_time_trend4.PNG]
  
</p>

<h3>9. Analysis</h3>
<p>The Analysis page provides a chart showing the daily energy consumption statistics for each load.</p>
<p>Trang Analysis cung cấp biểu đồ thống kê năng lượng tiêu thụ của từng Phân xưởng theo ngày.</p>
<p align="center">
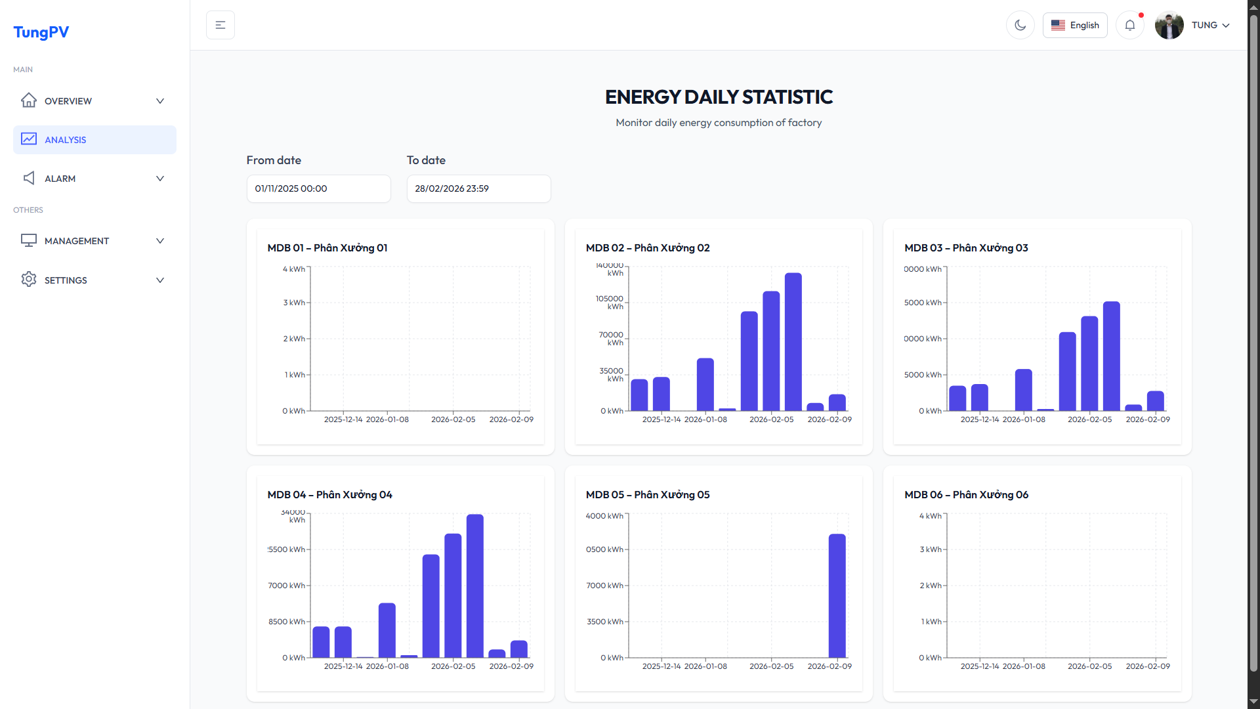
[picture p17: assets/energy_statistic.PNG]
  
</p>

<h3>10. Alarm</h3>
<p>The Alarm page allows users to set alarm thresholds for daily electricity usage. Specifically:</p>
<ul>
  <li>[A] amount of electricity used up to this point.</li>
  <li>[A0]amount of electricity used yesterday.</li>
  <li>Accumulated electricity during the day = A - A0.</li>
</ul>
<p>Trang Alarm cho phép người dùng cài đặt ngưỡng cảnh báo về mức sử dụng điện năng trong ngày. Trong đó:</p>
<ul>
  <li>[A] số điện năng đã tiêu thụ tính đến thời điểm hiện tại.</li>
  <li>[A0]số điện năng đã tiêu thụ ngày hôm qua.</li>
  <li>Điện năng tích lũy trong ngày = A - A0.</li>
</ul>
<p align="center">
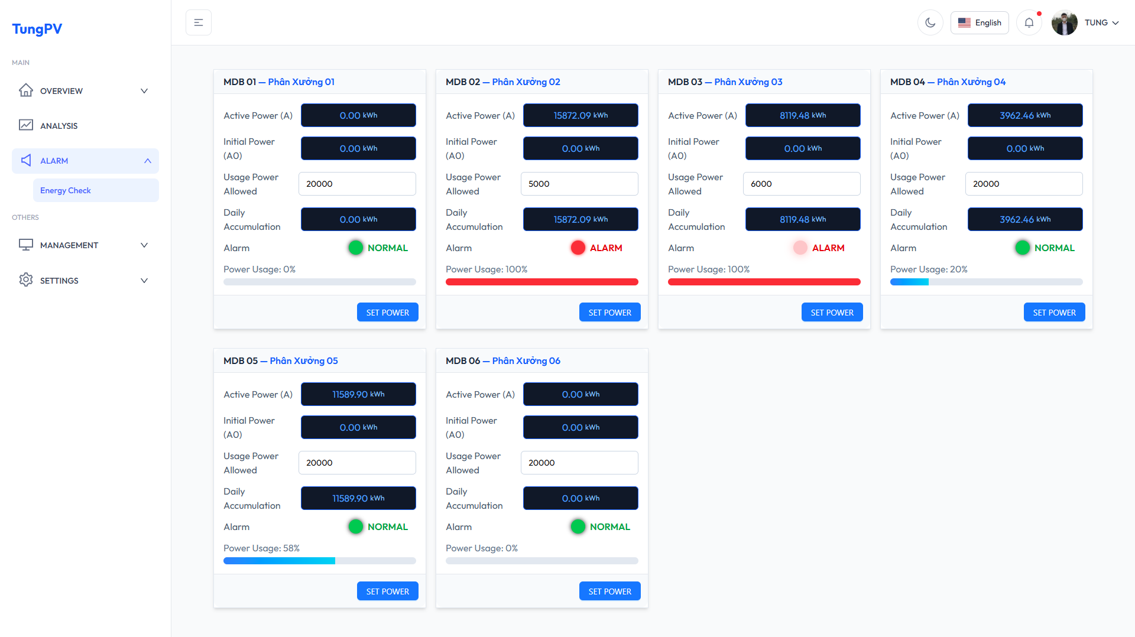
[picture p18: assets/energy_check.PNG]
  
</p>

<h3>11. Management</h3>
<p>Manages data on the installed capacity of each load, parameters of selected ACBs and MCCBs, account settings, along with search functionality combined with pagination.</p>
<p>Quản lý dữ liệu về công suất đặt của từng Phân xưởng, thông số của ACB, MCCB đã chọn, cài đặt tài khoản, cùng với chức năng tìm kiếm kết hợp phân trang.</p>
<p align="center">
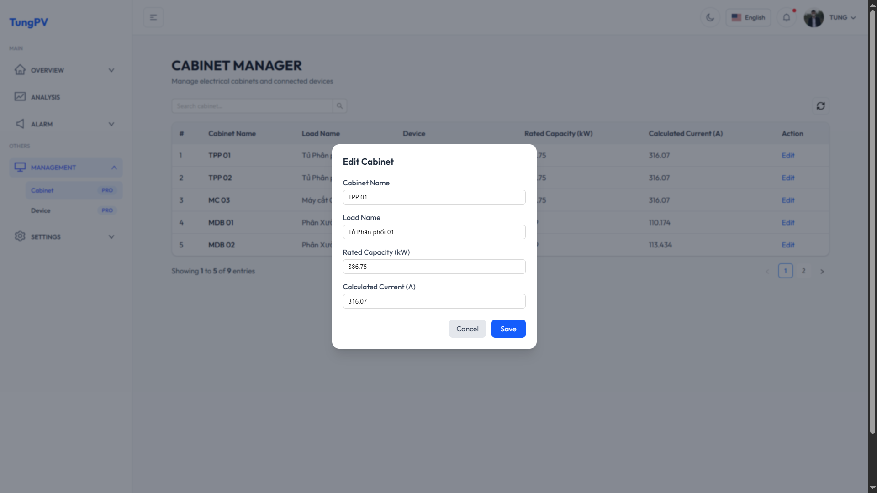
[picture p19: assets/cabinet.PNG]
  
</p>

</div>

# V. HIDDEN MARKOV MODEL AND ELECTRICITY USAGE FORECASTING SERVICE

<h3>1. Hidden Markov Model</h3>
<p>The Markov Model is a probabilistic model used to decrible the state of a system, where the future states depend only on the present, not on the past. Consider
a sequence of state variables q1, q2, ..., qi. Markov assumption: </p>

$$
P_{(q_i = \alpha | q_1, q_2, ..., q_i)} = P_{(q_i = \alpha | q_{i - 1})}
$$

<p>Components of the Markov Model: </p>
<p>- System states </p>

$$
S = \{ S_1, S_2, ..., S_n \}
$$

<p>- Initial probability distribution </p>

$$
\pi = \{ \pi_1, \pi_2, ..., \pi_n \}
$$

<p>- Transition probability matrix </p>

$$
P = \begin{bmatrix}
P_{11} & P_{12} & ... & P_{1n} \\
P_{21} & P_{22} & ... & P_{2n} \\
... & ... & ... & ... \\
P_{n1} & P_{n2} & ... & P_{nn} \\
\end{bmatrix}
$$

<p>And </p>

$$
\sum_{j=1}^{n} P_{ij} = 1
$$

<p>A Markov chain is useful when we need to compute a probability for a sequence
of observable events. In many cases, however, the events we are interested in are
hidden: we don’t observe them directly.</p>
<p>For example we don’t normally observe states in a UPS System. Rather, we see power comsumed, and must infer the states from the
state sequence. We call the states hidden because they are not observed.</p>

<p>Example of a Markov chain</p>

$$
O = \{ 1kWh, 2kWh, 2kWh, 3kWh,... \}
$$ 

<p>Infer the states then</p>

$$
S = \{ 1, 2, 2, 3,... \}
$$

<p>Hidden Markov models be featured by three fundamental problems:</p>
<ul>
  <li>Problem 1 (Likelihood): Given an HMM λ = (A,B) and an observation sequence O, determine the likelihood P(O|λ)</li>
  <li>Problem 2 (Decoding): Given as input an HMM λ = (A,B) and a sequence of observations O = o1,o2,...,oT , find the most probable sequence of states Q = q1q2q3...qT.</li>
  <li>Problem 3 (Training): Given an observation sequence O and the set of possible states in the HMM, learn the HMM parameters A and B.</li>
</ul>

<p>Mô hình Hidden Markov được đặc trưng bởi 3 bài toán chính:</p>
<ul>
  <li>Bài toán 1 (Likelihood): Cho ma trận chuyển trạng thái A và ma trận phát xạ B và một chuỗi các quan sát O, rồi sau đó tính likelihood. Dùng để so sánh giữa các mô hình, chọn ra mô hình có likelihood cao nhất</li>
  <li>Bài toán 2 (Decoding): Cho ma trận A và ma trận B và một chuỗi các quan sát O = o1,o2,...,oT , tìm chuỗi trạng thái ẩn tốt nhất, Q = q1q2q3...qT.</li>
  <li>Problem 3 (Training): Cho chuỗi các quan sát O, học ma trận A, B, π. Ma trận A và B sau đó được dùng cho bài toán 1 và 2.</li>
</ul>

<h3>2. Electricity usage forecasting service</h3>
<p>a. Dataset</p>

<p> We don't have enough data to train the model, so let reference dataset of UCI Machine Learning for model training. Please, refer to: https://www.kaggle.com/datasets/uciml/electric-power-consumption-data-set</p>
<p>This project selected 03 electrical parameters for training the model, that is: Global active power, Voltage, Global intensity</p>
<p>Vì không đủ dữ liệu để huấn luyện mô hình nên dự án tham khảo tập dữ liệu của UCI ML: https://www.kaggle.com/datasets/uciml/electric-power-consumption-data-set</p>
<p>Chọn ra 3 thông số điện để huấn luyện mô hình: Công suất tiêu thụ, điện áp, dòng điện của toàn Xí nghiệp trong mỗi giờ</p>
<p>b. The system consists of 04 states</p>
<ul>
  <li>S1 - LOWLOAD</li>
  <li>S2 - NORMAL</li>
  <li>S3 - WARNING</li>
  <li>S4 - OVERLOAD</li>
</ul>

<p>c. Initial probability distribution</p>

$$
\pi = \{ 0, 1, 0, 0 \}
$$

<p>d. Transition probability matrix</p>

$$
P = \begin{bmatrix}
0.76102974 & 0.01277457 & 0.21681042 & 0.00938528 \\
0.00495119 & 0.67550022 & 0.11157301 & 0.20797559 \\
0.26248165 & 0.09087763 & 0.48913395 & 0.15750676 \\
0.029213   & 0.08783518 & 0.21200698 & 0.67094483 \\
\end{bmatrix}
$$

<p>The transition probability matrix is a graph where each state is represented by a vertex. The transition probability is expressed for each arc with two vertices.</p>
<p>Assuming the power system is currently in state S2 (NORMAL), the predicted probability of the next state being S1 (LOWLOAD) is approximately 0.49%, remaining in S2 is 67.55%, S3 (WARNING) is 11.15%, and S4 (OVERLOAD) is 20.79%.</p>
<p>Ma trận chuyển trạng thái là một đồ thị mà mỗi trạng thái là một đỉnh của đồ thị và xác suất chuyển trạng thái là trọng số giữa 2 đỉnh.</p>
<p>Giả sử hệ thống điện đang ở trạng thái S2 (NORMAL). Trạng thái tiếp theo, xác suất để hệ thống chuyển sang S1 (LOWLOAD) là khoảng 0,49%, ở lại S2 là 67,55%, S3 (WARNING) là 11,15%, S4 (OVERLOAD) là 20,79%</p>
<p align="center">
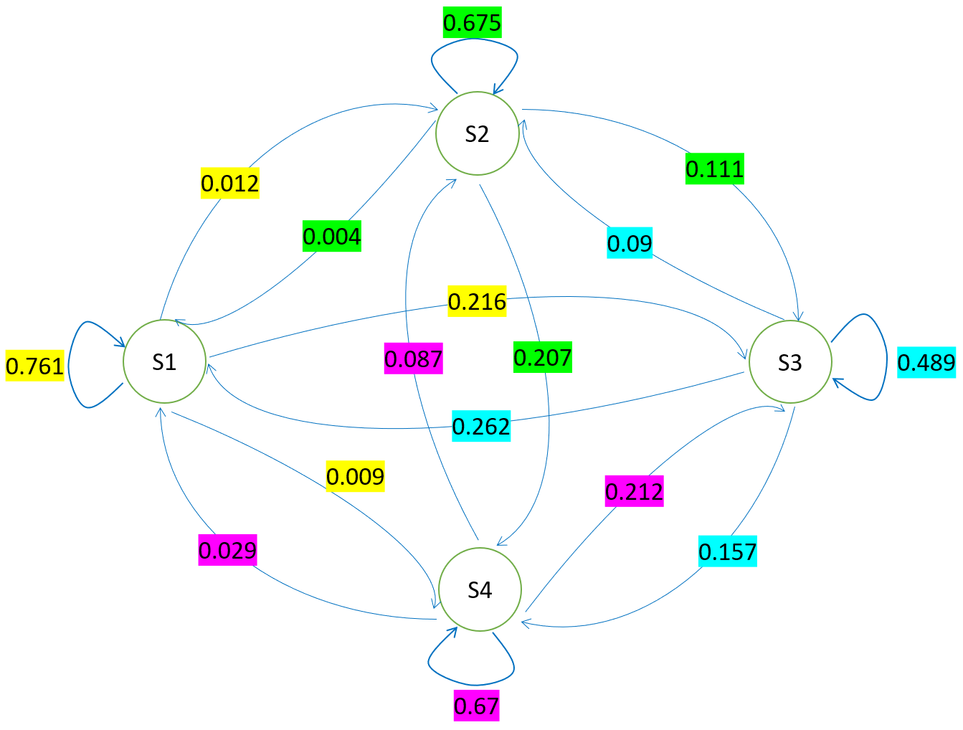
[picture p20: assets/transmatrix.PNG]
  
</p>

<p>e. Analysis the electricity usage on 15 February 2026</p>
<p>* Predict hidden states & Anomaly delection</p>
<p>Looking at the state chart for 15 February 2026, it shows that the power system operates at a normal level during the night and morning hours (0h - 8h). The peak electricity consumption periods are from around noon (11h - 16h) and evening (18h - 22h). After 22h, electricity consumption is low, indicating a day-night cycle within the system.</p>
<p>Biểu đồ trạng thái ngày 15-02-2026 cho thấy thời điểm từ đêm và sáng (0h - 8h) hệ thống điện hoạt động ở mức bình thường, từ khoảng trưa (11h - 16h) và chiều tối (18h - 22h) là khoảng thời gian cao điểm sử dụng điện. Sau 22h đêm là mức tiêu thụ điện thấp, cho thấy hệ thống có chu kì ngày và đêm.</p>
<p align="center">
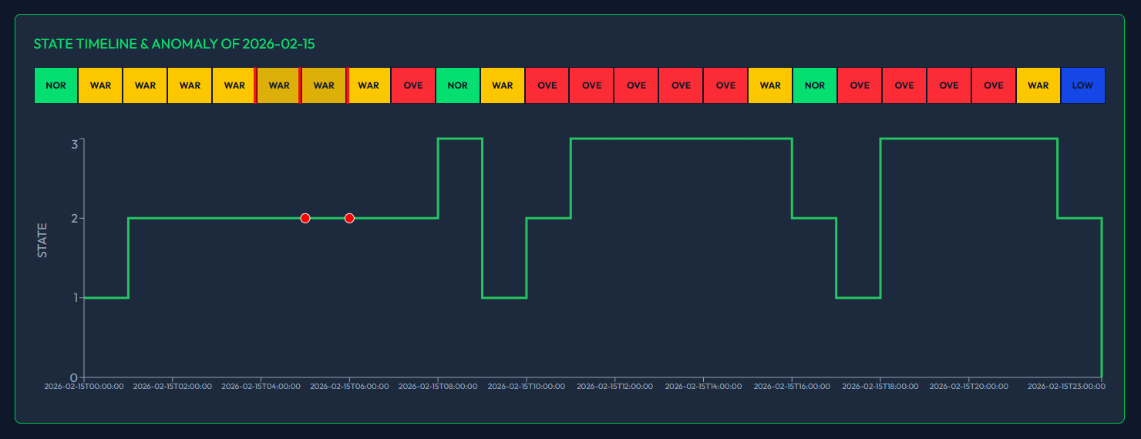
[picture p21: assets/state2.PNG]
  
</p>

<p>* Forecast of energy consumption for the next 24 hours (16 February 2026)</p>
<p>The model provides a forecast of electricity consumption over the next 24 hours. Looking at the graph, the trend is relatively flat, with an average electricity consumption of approximately 1.5 kW per hour.</p>
<p>Mô hình đưa ra dự báo về mức tiêu thụ điện năng trong 24h tiếp theo, nhìn vào biểu đồ cho thấy đồ thị tương đối phẳng, mức tiêu thụ điện năng ở mức thấp khoảng 1.5 kW mỗi giờ.</p>
<p align="center">
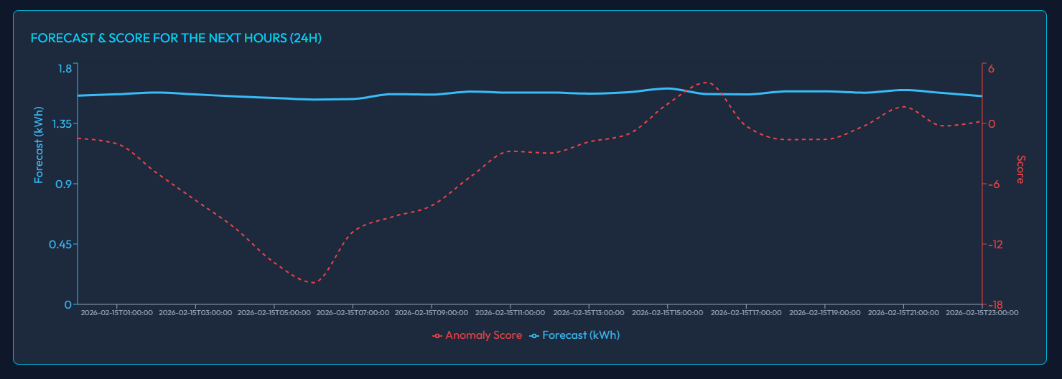
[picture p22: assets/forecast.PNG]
  
</p>

<p>f. Analysis the electricity usage on 16 February 2026</p>
<p>* Predict hidden states & Anomaly delection</p>
<p>Looking at the status chart for 16 February 2026, the system appears to be operating quite stably, with no peak periods during the day, as previously predicted.</p>
<p>Biểu đồ trạng thái ngày 16-02-2026 cho thấy hệ thống hoạt động khá ổn định, không có khoảng thời gian cao điểm trong ngày, như dự báo trước đó.</p>
<p align="center">
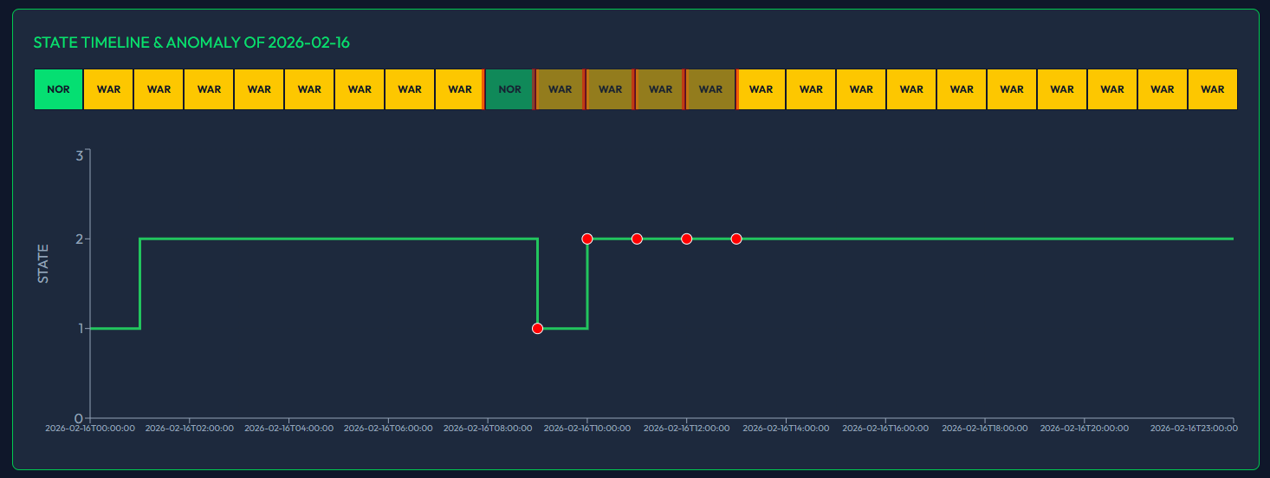
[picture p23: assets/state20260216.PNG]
  
</p>

<p>* Forecast of energy consumption for the next 24 hours (17 February 2026)</p>
<p>Forecasts for the next 24 hours indicate that electricity consumption may peak at noon (10:00 AM, 17 February 2026) at 46.21 kWh and at night (7:00 PM, 17 February 2026) at 47.09 kWh.</p>
<p>Dự báo trong 24h tiếp theo, mức sử dụng điện năng có thể đạt đỉnh điểm vào lúc trưa (10h 2026-02-17) với 46,21 kWh và tối (19h 17/02/2026) là 47,09 kWh.</p>
<p align="center">
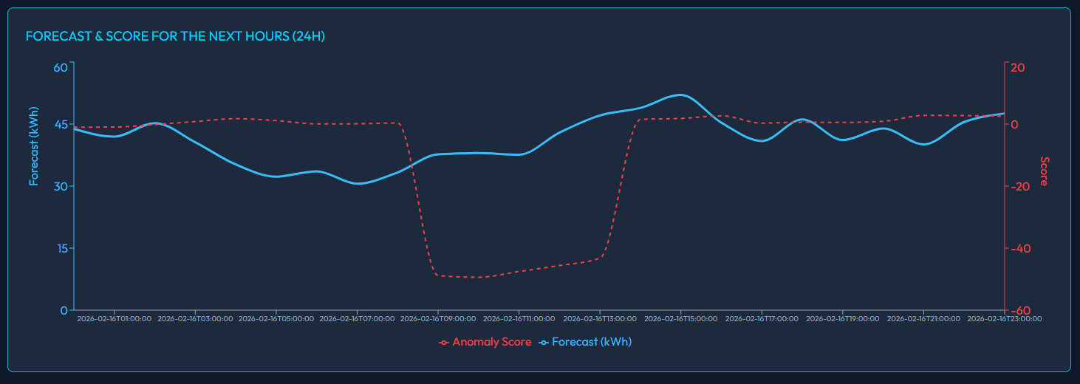
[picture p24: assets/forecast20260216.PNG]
  
</p>

https://github.com/user-attachments/assets/55879641-cb0f-49be-9f60-3ca826b1b9fb

# VI. DEMONSTRATION
<div>

<p align="center">
  <a href="https://www.youtube.com/watch?v=00z3u6Ofh6w&t=75s">
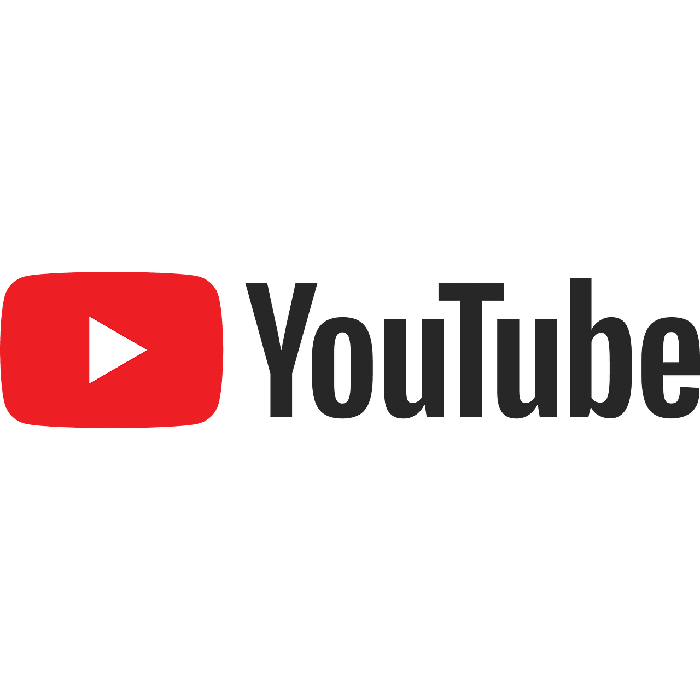
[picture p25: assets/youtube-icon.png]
PC Demo
    
  </a>
</p>

<h3>MOBILE FRIENDLY</h3>
<p align="center">
  <a href="https://www.youtube.com/watch?v=aQUQzm_U8xE">
    Mobile Demo
  </a>
</p>
 
</div>

# VII. REQUIREMENTS
<div>
<p>Back-end</p>
<ul>
  <li>Spring Boot 3.5.6</li>
  <li>Tomcat server 10.1.31</li>
  <li>MySQL</li>
  <li>Redis</li>
  <li>Spring Boot Security</li>
  <li>Spring Boot WebSocket</li>
  <li>Spring Data JPA</li>
  <li>Hibernate core 6.6.18</li>
  <li>Lombok</li>
  <li>Spring Boot Validation</li>
  <li>Json Webtoken 0.9.1</li>
</ul>
<p>Front-end</p>
<ul>
  <li>React 18.3.1</li>
  <li>Docker</li>
  <li>Axios 1.13.2</li>
  <li>React redux 9.2.0</li>
  <li>React router 7.9.6</li>
  <li>React charts 3.5.1</li>
  <li>Sockjs client 1.6.1</li>
  <li>Ant design 5.28.1</li>
  <li>Vite Tailwindcss 4.1.17</li>
</ul>
<p>Forecast service</p>
<ul>
  <li>hmmlearn 0.3.3</li>
  <li>Docker</li>
  <li>numpy</li>
  <li>pandas</li>
  <li>scikit-learn 1.7.2</li>
  <li>fastapi 0.129.0</li>
  <li>joblib 1.5.3</li>
  <li>pydantic 2.12.5</li>
</ul>

# VIII. REFERENCES
<p>[1] Cuốn Bài tập Cung Cấp Điện - TS. Trần Quang Khánh</p>
<p>[2] Hidden Markov Model - Speech and Language Processing. Daniel Jurafsky & James H. Martin. https://web.stanford.edu/~jurafsky/slp3/A.pdf</p>
<p>[3] Household Electric Power Consumption - UCI Machine Learning. https://www.kaggle.com/datasets/uciml/electric-power-consumption-data-set</p>

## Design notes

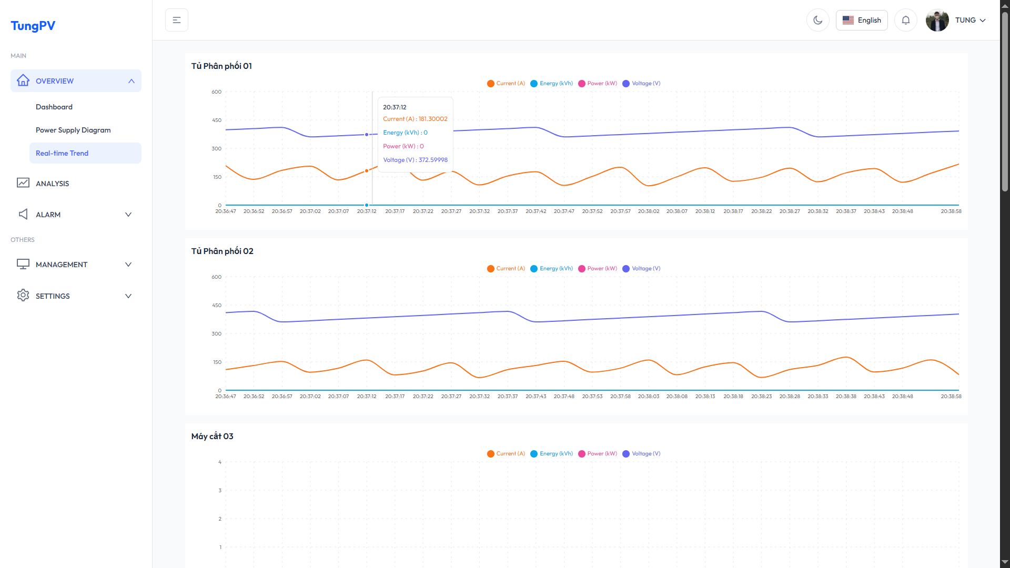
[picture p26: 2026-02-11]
assets/real_time_trend3.PNG

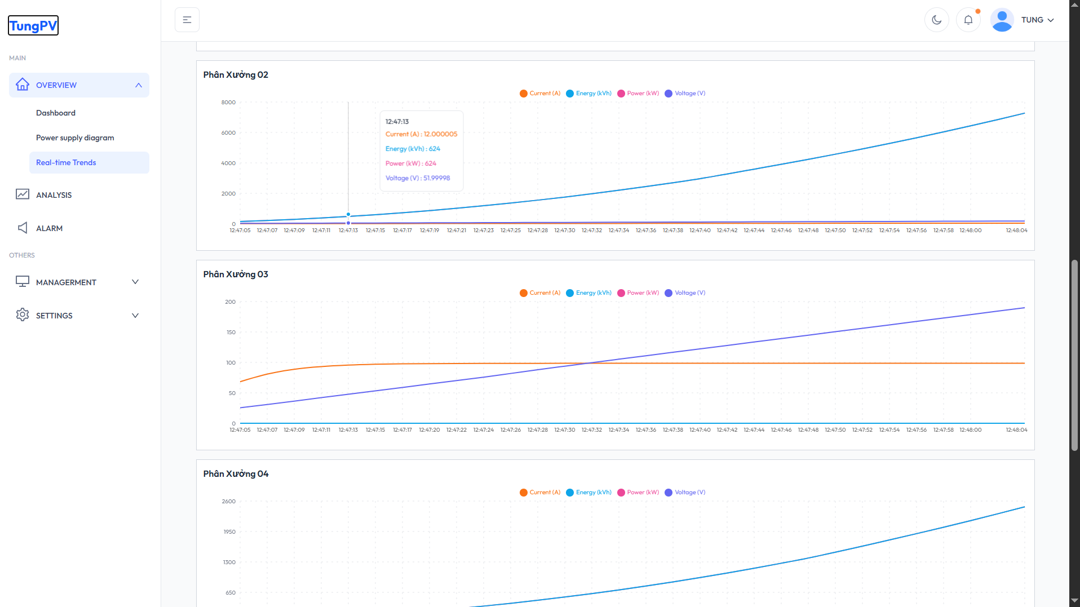
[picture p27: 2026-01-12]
assets/real_time_trend.PNG

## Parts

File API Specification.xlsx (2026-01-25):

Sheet: API SPEC
PLC <--> SERVER | Field | STX | HEADER |  | PAYLOAD |  |  |  |  |  | ETX
 |  |  | MSG_TYPE | PAYLOAD_LENGTH | DEVICE_ID | CURRENT | VOLTAGE | POWER | ENERGY CONSUMPTION | STATUS
1. PLC --> SERVER | Number of Bytes | 2 | 4 | 2 | 2 | 4 | 4 | 4 | 4 | 2 | 1
 | Data type | word/short | string | word/short | word/short | float | float | float | float | word/short | byte
 | Values | 0x02 | DEEN: Device energy | 20 | 1: ACB 01 2: ACB 02 3: ACB 03 4: MCCB 01 5: MCCB 02 6: MCCB 03 7: MCCB 04 8: MCCB 05 9: MCCB 06 | 0 | 0 | 0 | 0 | 1: CLOSED 2: OPENED 3. ERROR | 0x03
 | Message length | 29
2. SERVER --> PLC | Field |  |  |  | DEVICE_ID | COMMAND
 | Number of Bytes |  |  |  | 2 | 2 | 0 | 0 | 0 | 0
 | Data type |  |  |  | word/short | word/short
 | Values |  | DECO: Device command | 4 | 1: ACB 01 2: ACB 02 3: ACB 03 | 1: CLOSED 2: OPENED
 | Message length | 13
3. PLC --> SERVER | Field |  |  |  | DEVICE_ID | RESULT
 | Number of Bytes |  |  |  | 2 | 2 | 0 | 0 | 0 | 0
 | Data type |  |  |  | word/short | word/short
 | Values |  | DERE: Device response | 4 | 1: MBA1 2: MBA2 3: MBA3 | 1: OK 2: NG
 | Message length | 13
4. SERVER --> PLC | Field |  |  |  | COMMAND
 | Number of Bytes |  |  |  | 2 | 0 | 0 | 0 | 0 | 0
 | Data type |  |  |  | word/short
 | Values |  | MOCO: Mode command | 2 | 1: Auto 2: Manual
 | Total frame size | 11
5. PLC --> SERVER | Field |  |  |  | MODE
 | Number of Bytes |  |  |  | 2 | 0 | 0 | 0 | 0 | 0
 | Data type |  |  |  | word/short
 | Values |  | MORE: Mode response | 2 | 1: Auto 2: Manual
 | Message length | 11

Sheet: Mapping
D REGISTERS |  |  |  | M REGISTERS
Device name | Description |  |  | Device name | Description
D50 | Status ACB 01
D51 | Status ACB 02
D52 | Status ACB 03
D53 | Status MCCB 01
D54 | Status MCCB 02
D55 | Status MCCB 03
D56 | Status MCCB 04
D57 | Status MCCB 05
D58 | Status MCCB 06
D70 | MODE
D100 | Open connection |  |  | M100 | Open connection status
 |  |  |  | M101
D110 | DECO DATA
D200 | Close connection
 |  |  |  | M110 | STEP 1
 |  |  |  | M111 | STEP 2
D300 | Length of data |  |  | M112 | STEP 3
D301 | STX |  |  | M113 | STEP 4
D302 | MSG_TYPE |  |  | M114 | STEP 5
D303 |  |  |  | M115 | STEP 6
D304 | DEVICE_ID |  |  | M116 | STEP 7
D305 | SEQ_NUMBER |  |  | M117 | STEP 8
D306 | CURRENT |  |  | M118 | STEP 9
D307 |  |  |  | M119 | STEP 10
D308 | VOLTAGE |  |  | M120 | STEP 11
D309 |  |  |  | M121 | STEP 12
D310 | POWER_CONSUMPTION |  |  | M122 | STEP 13
D311 |  |  |  | M123 | STEP 14
D312 | ELECTRIC_CONSUMPTION |  |  | M124 | STEP 15
D313 |  |  |  | M125 | STEP 16
D314 | STATUS |  |  | M126 | MANUAL STEP
D315 | ETX |  |  | M127 | DECO STATUS
D500 | Data received
D550 | MSG_TYPE
D600 | Message type QF1 |  |  | M200 | Close connection status
D601 |  |  |  | M201
D602
D603
D604 | Device Id QF1 |  |  | M300 | Sending data status
D605 | Sequence number QF1 |  |  | M301
D606 | Current QF1
D607
D608
D609 |  |  |  | M400
D610 | Voltage QF1
D611 |  |  |  | M500 | Receiving data status
D612 |  |  |  | M501
D613 |  |  |  | M502
D614 | Power consumption QF1
D615
D616
D617
D618 | Electric consumption QF1 |  |  | M600 | Status QF1
D619 |  |  |  | M601 | Status QF2
D620 |  |  |  | M602 | Status QF3
D621 |  |  |  | M603 | Status SF1
D622 |  |  |  | M604 | Status SF2
D623 |  |  |  | M605 | Status SF3
D624 |  |  |  | M606 | Status SF4
D625 |  |  |  | M607 | Status SF5
D626 |  |  |  | M608 | Status SF6
D627 |  |  |  | M609 | Status SF7
D628 |  |  |  | M610 | Status SF8
D629
D630 | Message type QF2
D631
D632
D633
D634 | Device Id QF2
D635 | Sequence number QF2
D636 | Current QF2
D637
D638
D639
D640 | Voltage QF2
D641
D642
D643
D644 | Power consumption QF2
D645
D646
D647
D648 | Electric consumption QF2
D649
D650
D651
D652
D653
D654
D655
D656
D657
D658
D659
D660 | Message type QF3
D661 |  |  |  | M1000 | Socket open button
D662 |  |  |  | M1001 | Not used
D663 |  |  |  | M1002 | Socket Open normally
D664 | Device Id QF3 |  |  | M1003 | Socket Open error
D665 | Sequence number QF3
D666 | Current QF3
D667 |  |  |  | M3000 | Send data button
D668 |  |  |  | M3001
D669 |  |  |  | M3002 | Sending data normal
D670 | Voltage QF3 |  |  | M3003 | Sending data error
D671
D672
D673
D674 | Power consumption QF3
D675
D676
D677
D678 | Electric consumption QF3
D679
D680 |  |  |  | M4000 | Close socket button
D681 |  |  |  | M4001
D682 |  |  |  | M4002
D683 |  |  |  | M4003
D684 |  |  |  | M4004 | Closing flag
D685
D686
D687
D688
D689 |  |  |  | M5002 | Receiving data normal
D690 | Message type SF1 | D810 | Message type SF5 | M5003 | Receiving data error
D691 |  | D811
D692 |  | D812
D693 |  | D813
D694 | Device Id SF1 | D814 | Device Id SF5
D695 | Sequence number SF1 | D815 | Sequence number SF5
D696 | Current SF1 | D816 | Current SF5
D697 |  | D817
D698 |  | D818
D699 |  | D819
D700 | Voltage SF1 | D820 | Voltage SF5
D701 |  | D821
D702 |  | D822
D703 |  | D823
D704 | Power consumption SF1 | D824 | Power consumption SF5
D705 |  | D825
D706 |  | D826
D707 |  | D827
D708 | Electric consumption SF1 | D828 | Electric consumption SF5
D709 |  | D829
D710 |  | D830
D711 |  | D831
D712 |  | D832
D713 |  | D833
D714 |  | D834
D715 |  | D835
D716 |  | D836
D717 |  | D837
D718 |  | D838
D719 |  | D839
D720 | Message type SF2 | D840 | Message type SF6
D721 |  | D841
D722 |  | D842
D723 |  | D843
D724 | Device Id SF2 | D844 | Device Id SF6
D725 | Sequence number SF2 | D845 | Sequence number SF6
D726 | Current SF2 | D846 | Current SF6
D727 |  | D847
D728 |  | D848
D729 |  | D849
D730 | Voltage SF2 | D850 | Voltage SF6
D731 |  | D851
D732 |  | D852
D733 |  | D853
D734 | Power consumption SF2 | D854 | Power consumption SF6
D735 |  | D855
D736 |  | D856
D737 |  | D857
D738 | Electric consumption SF2 | D858 | Electric consumption SF6
D739 |  | D859
D740 |  | D860
D741 |  | D861
D742 |  | D862
D743 |  | D863
D744 |  | D864
D745 |  | D865
D746 |  | D866
D747 |  | D867
D748 |  | D868
D749 |  | D869
D750 | Message type SF3 | D870 | Message type SF7
D751 |  | D871
D752 |  | D872
D753 |  | D873
D754 | Device Id SF3 | D874 | Device Id SF3
D755 | Sequence number SF3 | D875 | Sequence number SF7
D756 | Current SF3 | D876 | Current SF7
D757 |  | D877
D758 |  | D878
D759 |  | D879
D760 | Voltage SF3 | D880 | Voltage SF7
D761 |  | D881
D762 |  | D882
D763 |  | D883
D764 | Power consumption SF3 | D884 | Power consumption SF7
D765 |  | D885
D766 |  | D886
D767 |  | D887
D768 | Electric consumption SF3 | D888 | Electric consumption SF7
D769 |  | D889
D770 |  | D890
D771 |  | D891
D772 |  | D892
D773 |  | D893
D774 |  | D894
D775 |  | D895
D776 |  | D896
D777 |  | D897
D778 |  | D898
D779 |  | D899
D780 | Message type SF4 | D900 | Message type SF8
D781 |  | D901
D782 |  | D902
D783 |  | D903
D784 | Device Id SF4 | D904 | Device Id SF8
D785 | Sequence number SF4 | D905 | Sequence number SF8
D786 | Current SF4 | D906 | Current SF8
D787 |  | D907
D788 |  | D908
D789 |  | D909
D790 | Voltage SF4 | D910 | Voltage SF8
D791 |  | D911
D792 |  | D912
D793 |  | D913
D794 | Power consumption SF4 | D914 | Power consumption SF8
D795 |  | D915
D796 |  | D916
D797 |  | D917
D798 | Electric consumption SF4 | D918 | Electric consumption SF8
D799 |  | D919
D800 |  | D920
D801 |  | D921
D802 |  | D922
D803 |  | D923
D804 |  | D924
D805 |  | D925
D806 |  | D926
D807 |  | D927
D808 |  | D928
D809 |  | D929
D3000 | Data send
D5000

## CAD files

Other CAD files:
004 Drawing/distribution_station_principle.dwg
004 Drawing/electrical_cabinet_layout.dwg
004 Drawing/wiring.dwg

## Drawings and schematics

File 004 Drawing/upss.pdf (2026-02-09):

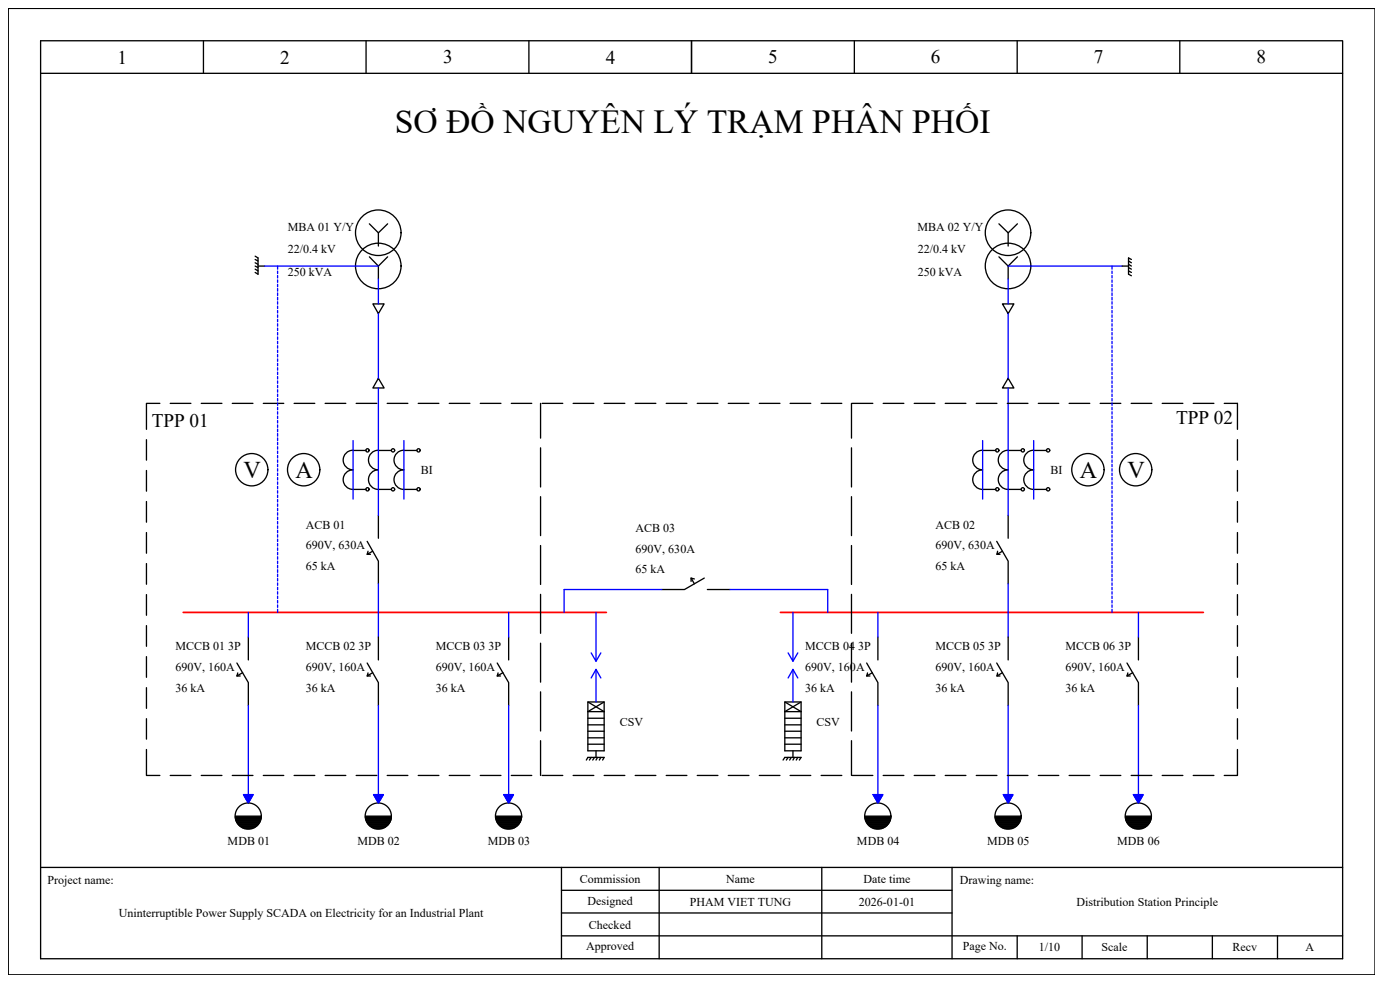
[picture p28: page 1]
8 Project name:; Designed Checked Approved; Name; Date time; Drawing name: Page No.; Scale; Recv Commission; A PHAM VIET TUNG; Distribution Station Principle Uninterruptible Power Supply SCADA on Electricity for an Industrial Plant; SƠ ĐỒ NGUYÊN LÝ TRẠM PHÂN PHỐI MBA 01 Y/Y 22/0.4 kV 250 kVA 65 kA 690V, 630A ACB 01 36 kA 690V, 160A MCCB 01 3P; 36 kA 690V, 160A MCCB 02 3P; 36 kA 690V, 160A MCCB 03 3P MDB 01; MDB 02; MDB 03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

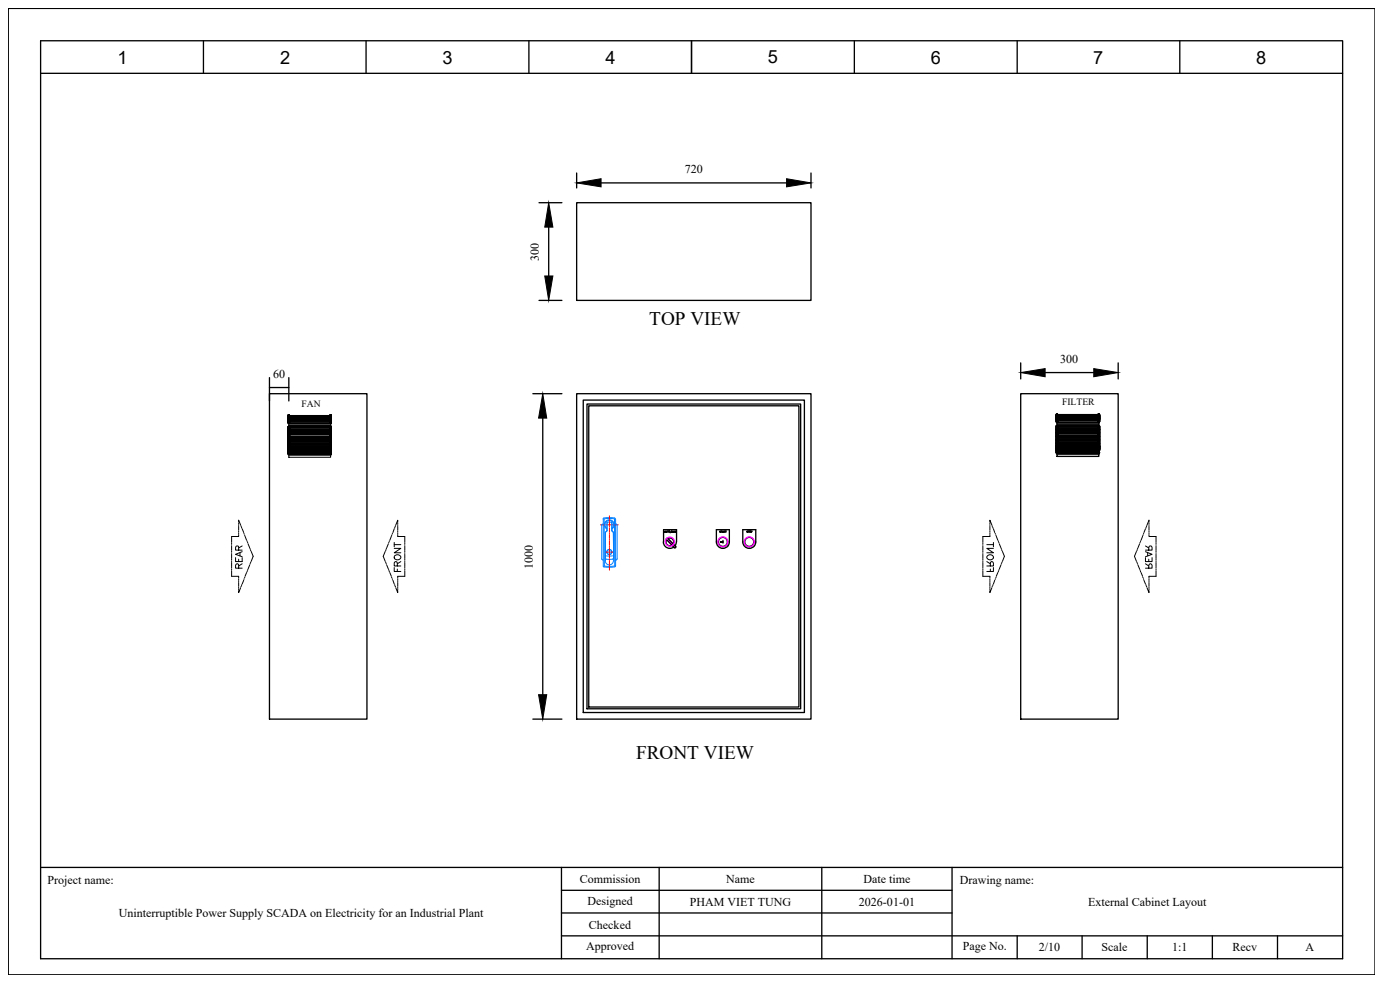
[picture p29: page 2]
8 Project name:; Designed Checked Approved; Name; Date time; Drawing name: Page No.; Scale; Recv Commission; A PHAM VIET TUNG; External Cabinet Layout Uninterruptible Power Supply SCADA on Electricity for an Industrial Plant FAN; FILTER TOP VIEW FRONT VIEW

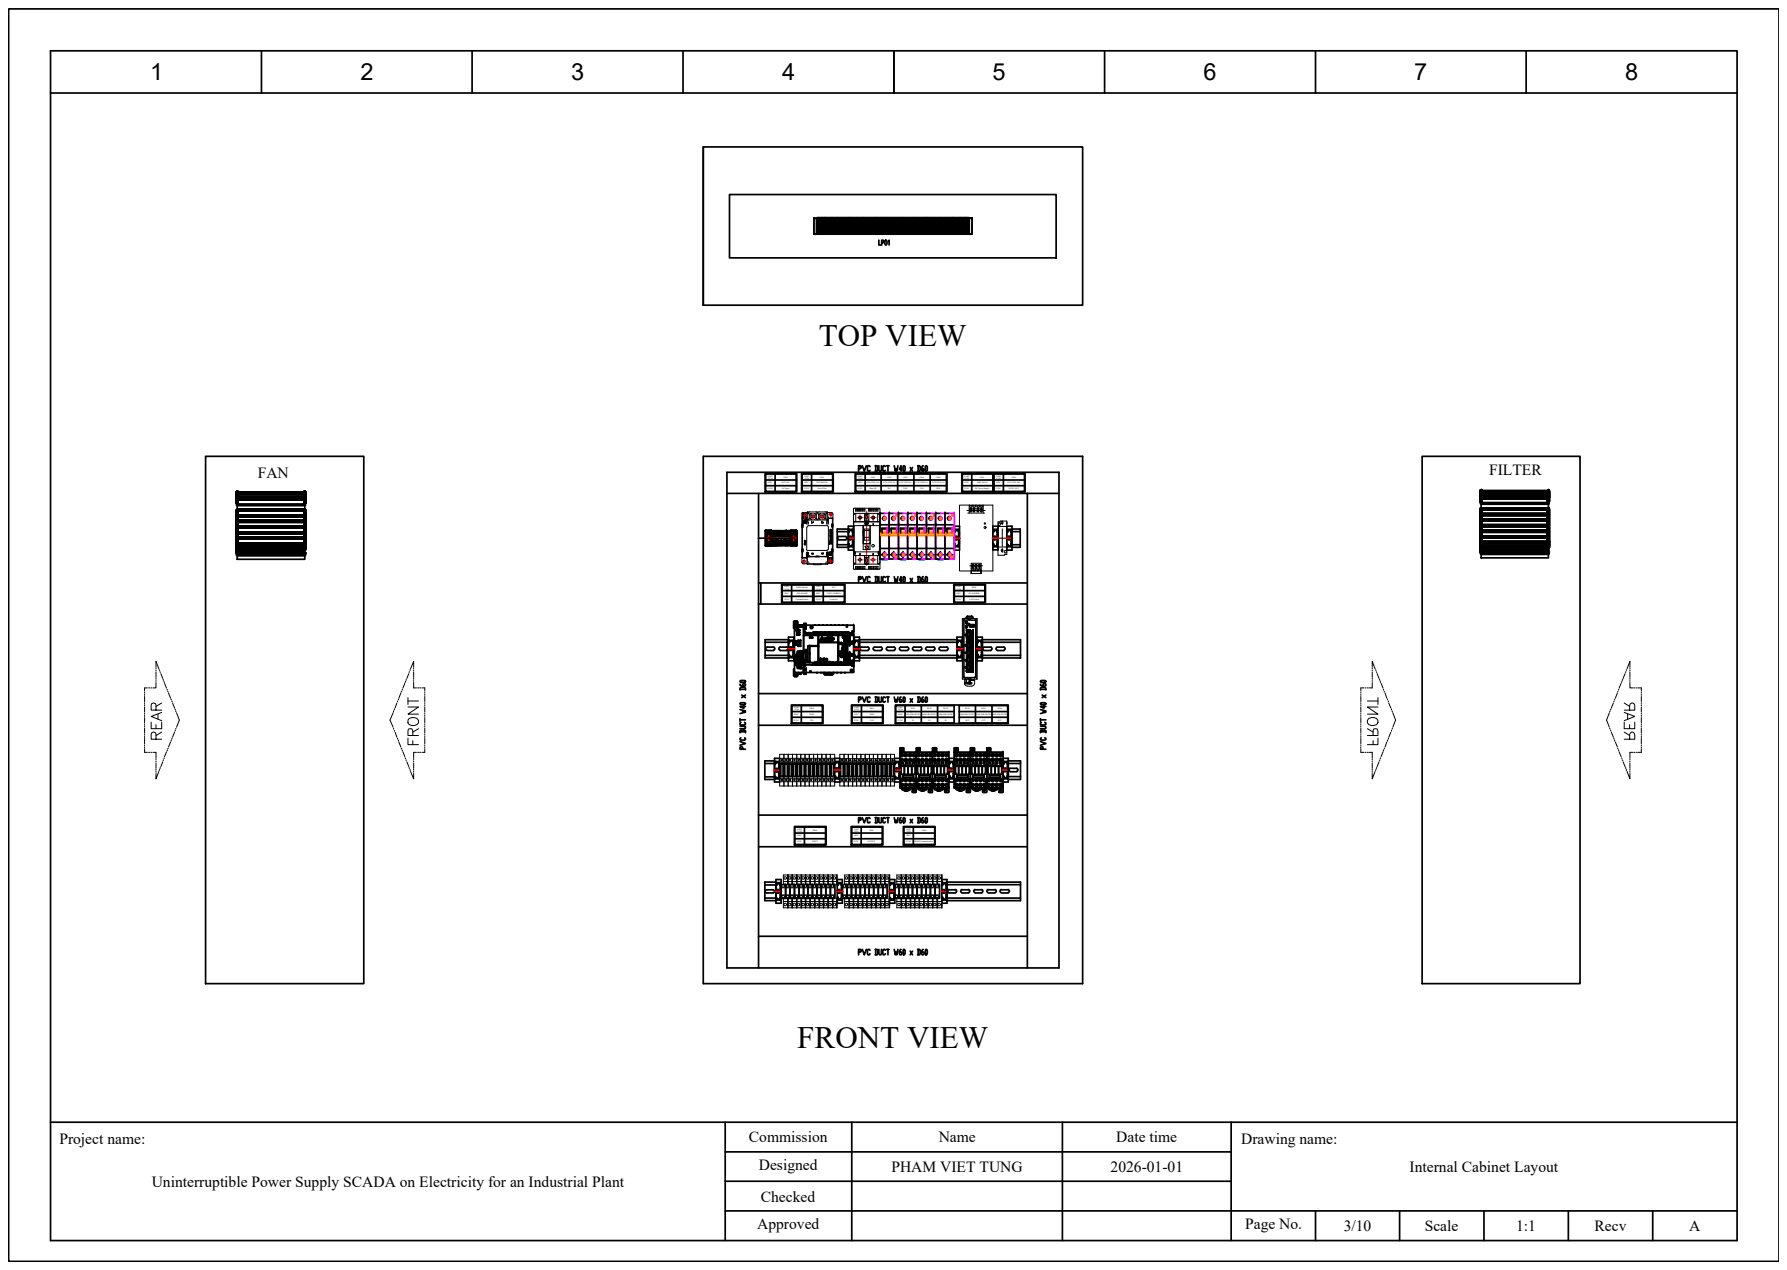
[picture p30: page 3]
8 Project name:; Designed Checked Approved; Name; Date time; Drawing name: Page No.; Scale; Recv Commission; A PHAM VIET TUNG; Internal Cabinet Layout Uninterruptible Power Supply SCADA on Electricity for an Industrial Plant FAN; FILTER TOP VIEW FRONT VIEW ¹ PART NUM SPEC FUNC; AC Input HYT-203 TB01; PART NUM SPEC FUNC; Noise Filter WYFS06T1M NF01; DC Power Supply NDR-240-24 PS01; 24VDC-OUT LCP-31FM-10A CB06 PART NUM SPEC FUNC; Communication FX5-485ADP RS485 Module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

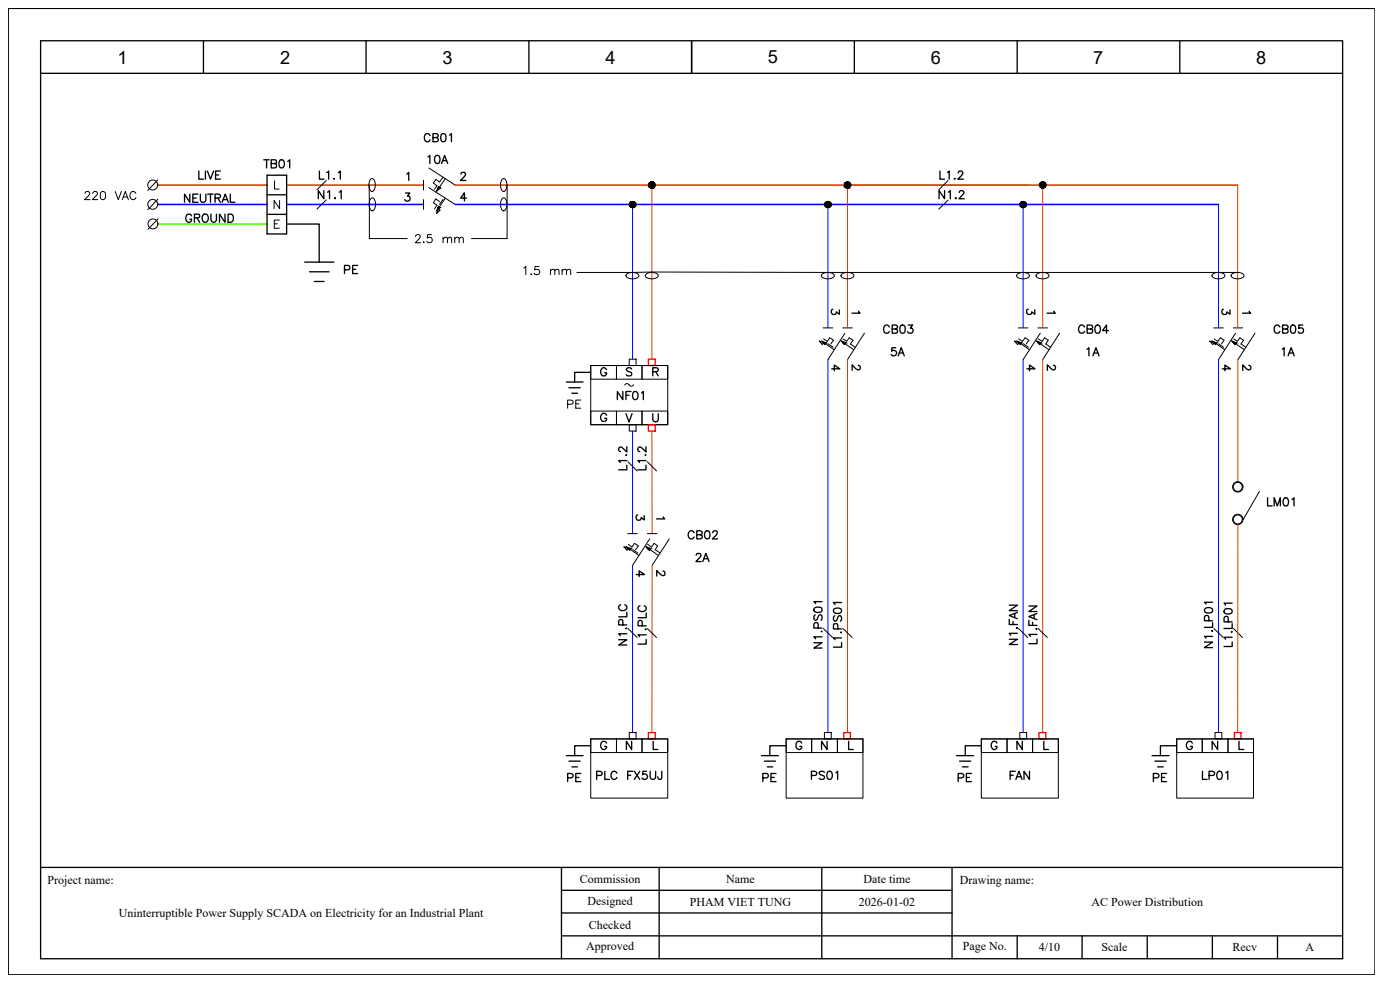
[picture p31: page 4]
8 Project name:; Designed Checked Approved; Name; Date time; Drawing name: Page No.; Scale; Recv Commission; A PHAM VIET TUNG; AC Power Distribution Uninterruptible Power Supply SCADA on Electricity for an Industrial Plant

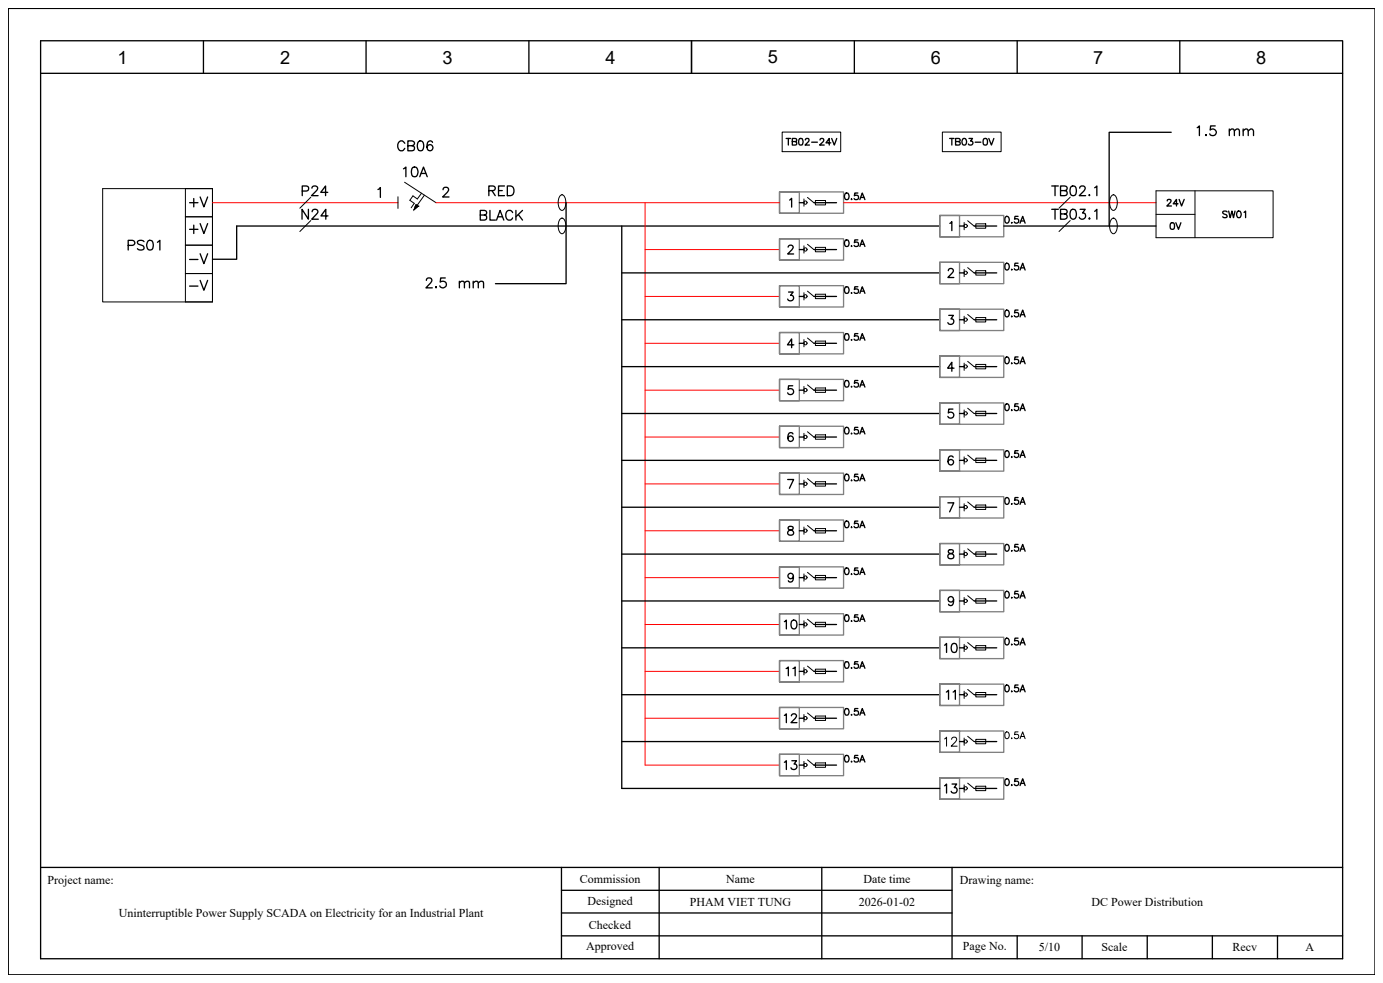
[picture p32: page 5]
8 Project name:; Designed Checked Approved; Name; Date time; Drawing name: Page No.; Scale; Recv Commission; A PHAM VIET TUNG; DC Power Distribution Uninterruptible Power Supply SCADA on Electricity for an Industrial Plant

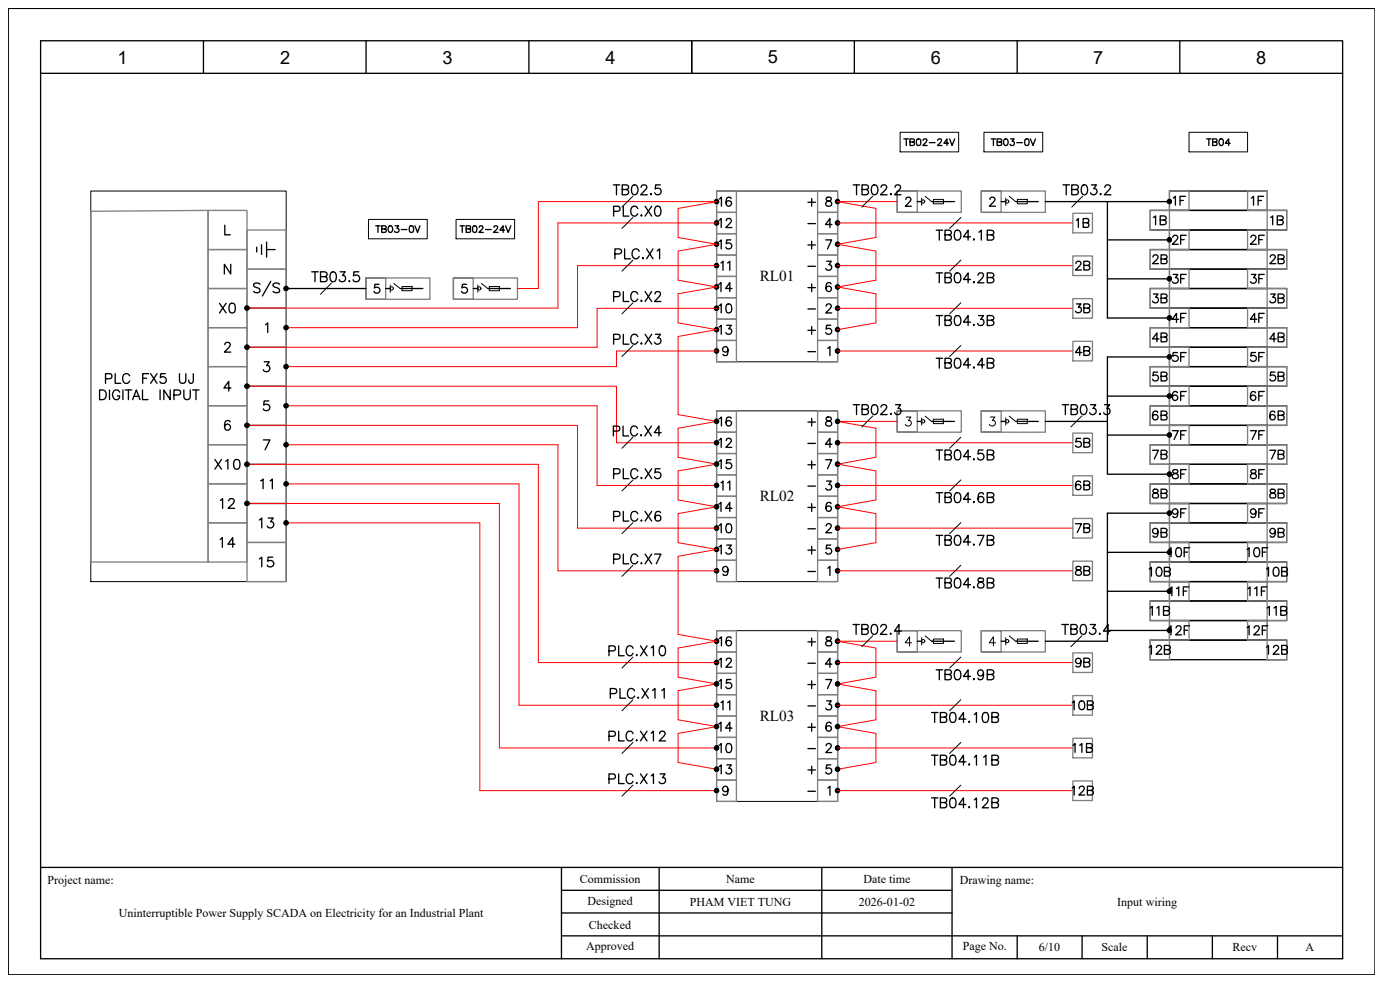
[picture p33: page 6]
8 Project name:; Designed Checked Approved; Name; Date time; Drawing name: Page No.; Scale; Recv Commission; A PHAM VIET TUNG; Input wiring Uninterruptible Power Supply SCADA on Electricity for an Industrial Plant

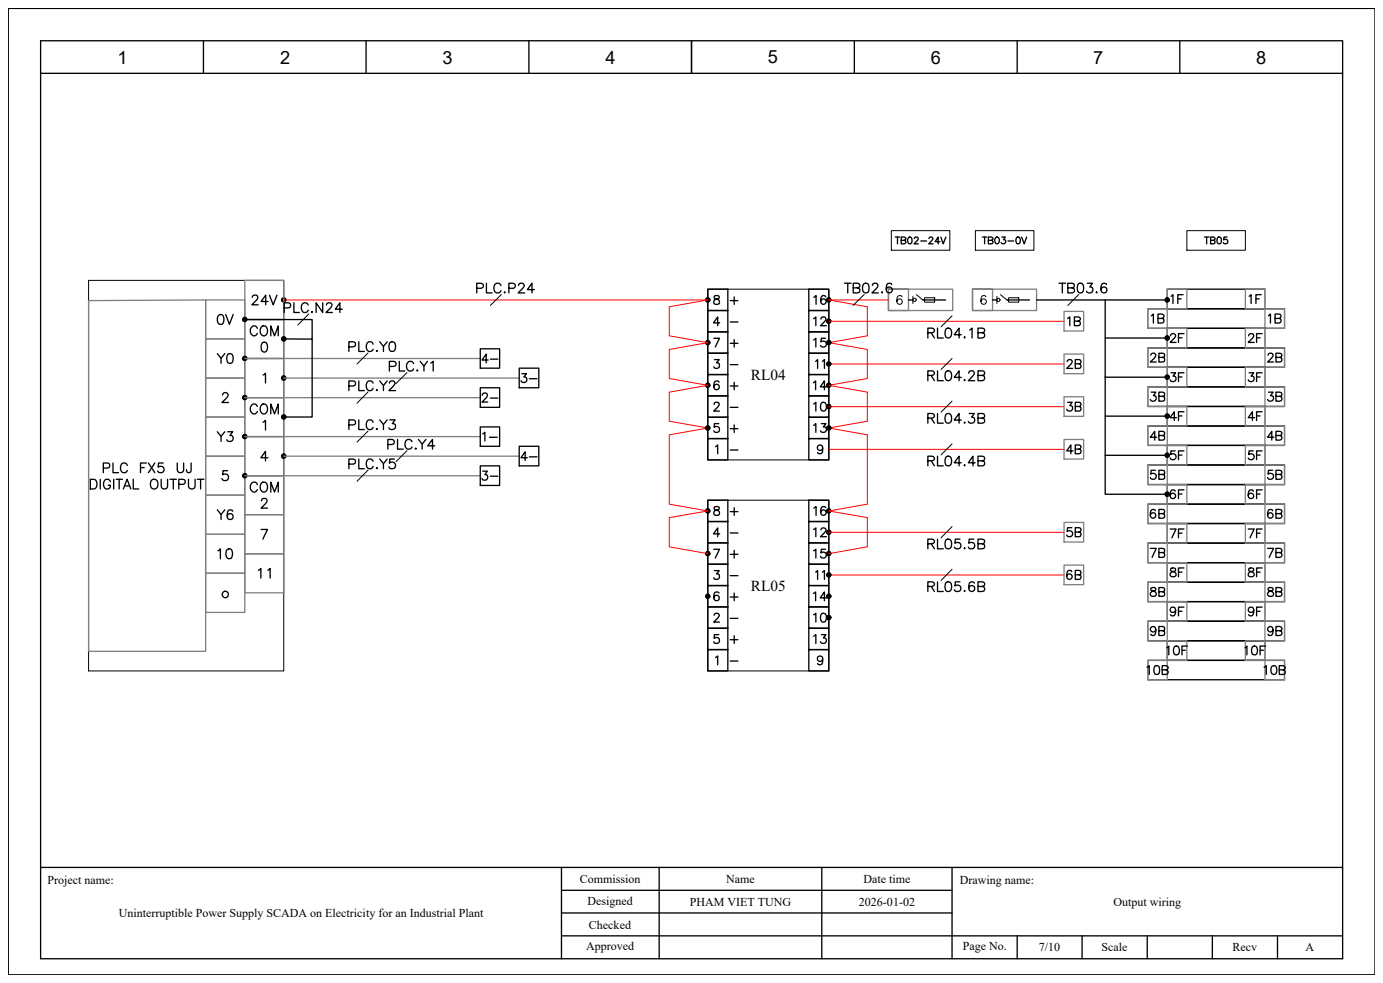
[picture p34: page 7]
8 Project name:; Designed Checked Approved; Name; Date time; Drawing name: Page No.; Scale; Recv Commission; A PHAM VIET TUNG; Output wiring Uninterruptible Power Supply SCADA on Electricity for an Industrial Plant

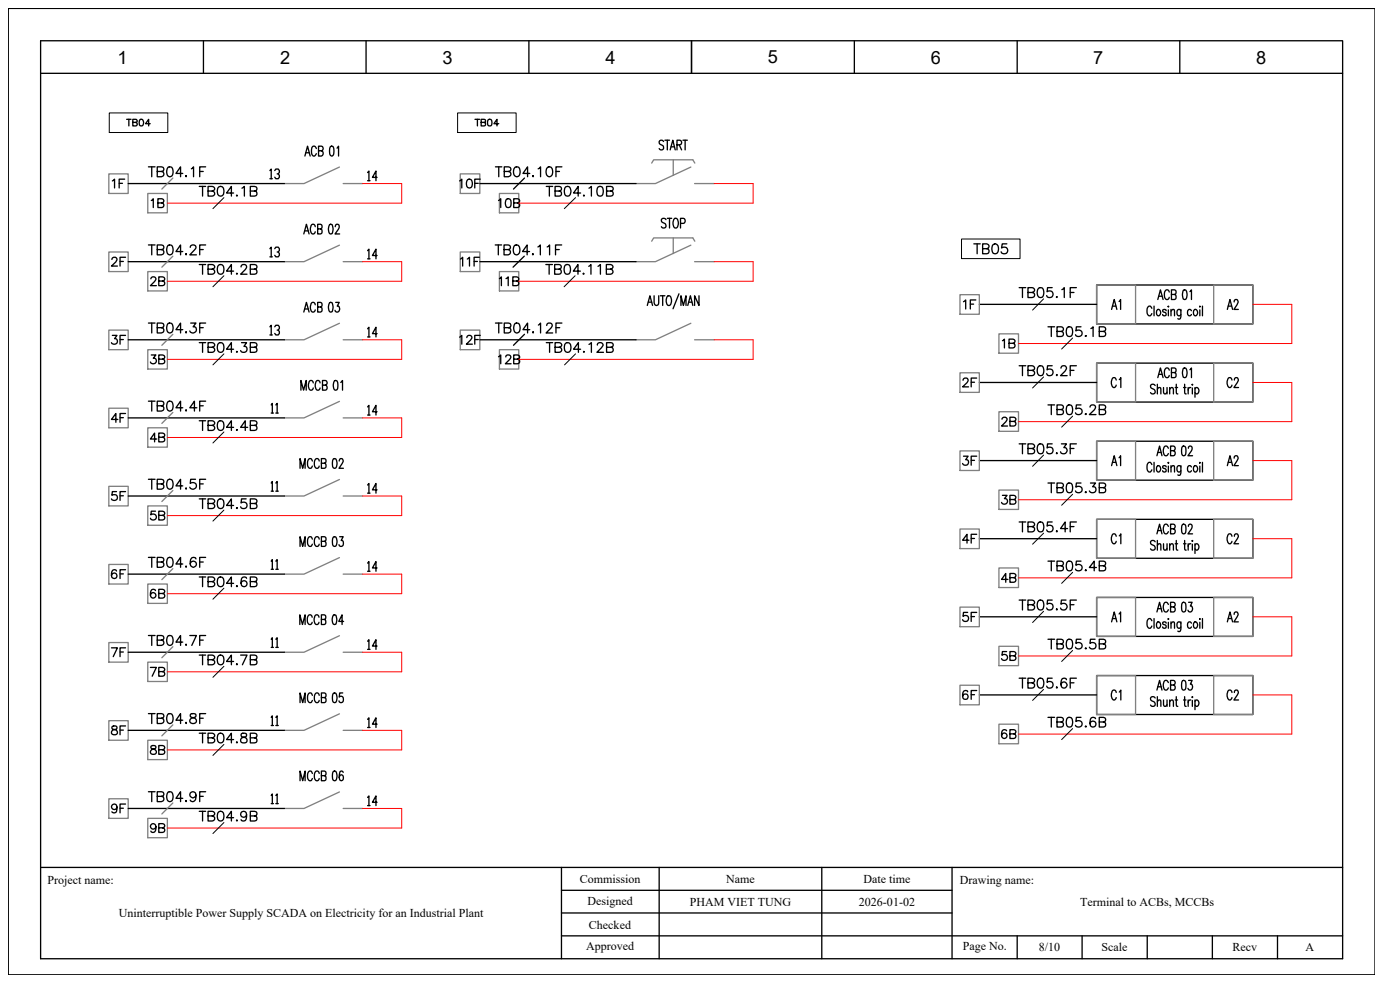
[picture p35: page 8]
8 Project name:; Designed Checked Approved; Name; Date time; Drawing name: Page No.; Scale; Recv Commission; A PHAM VIET TUNG; Terminal to ACBs, MCCBs Uninterruptible Power Supply SCADA on Electricity for an Industrial Plant

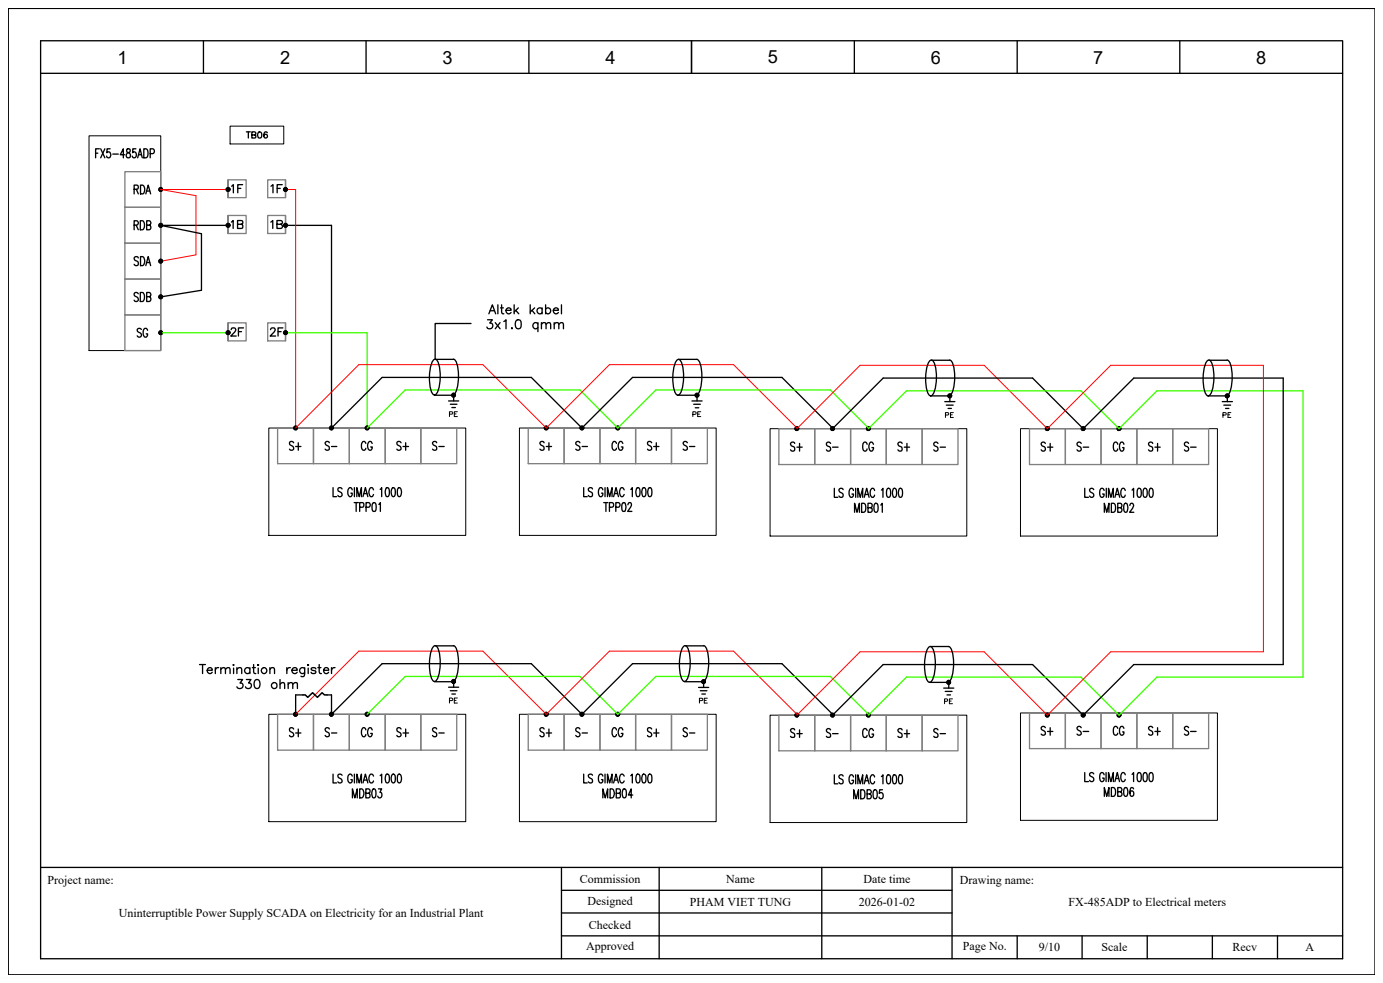
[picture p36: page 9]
8 Project name:; Designed Checked Approved; Name; Date time; Drawing name: Page No.; Scale; Recv Commission; A PHAM VIET TUNG; FX-485ADP to Electrical meters Uninterruptible Power Supply SCADA on Electricity for an Industrial Plant

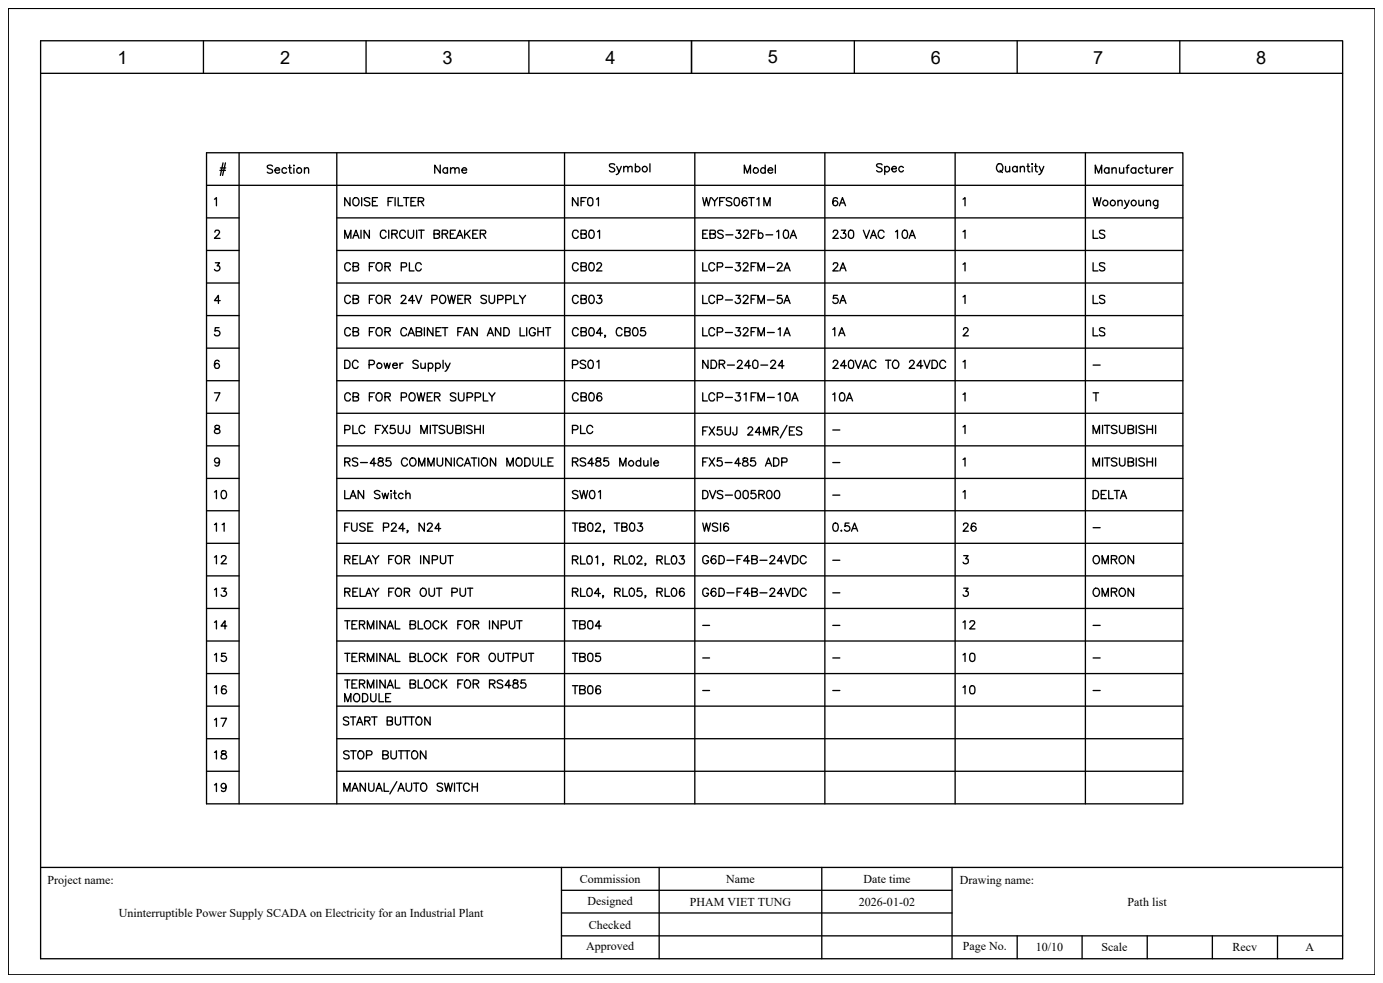
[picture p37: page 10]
8 Project name:; Designed Checked Approved; Name; Date time; Drawing name: Page No.; Scale; Recv Commission; A PHAM VIET TUNG; Path list Uninterruptible Power Supply SCADA on Electricity for an Industrial Plant

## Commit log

2026-01-12 add project
    [API Specification.xlsx, Configure.xlsx, distribution_station_principle.dwg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]
2026-01-19 update path list
    [wiring.dwg]
2026-01-25 update 20262501
    [API Specification.xlsx]
2026-02-09 update 20260209
    [distribution_station_principle.dwg, electrical_cabinet_layout.dwg, wiring.dwg]
2026-02-11 update project
    [Configure.xlsx]
